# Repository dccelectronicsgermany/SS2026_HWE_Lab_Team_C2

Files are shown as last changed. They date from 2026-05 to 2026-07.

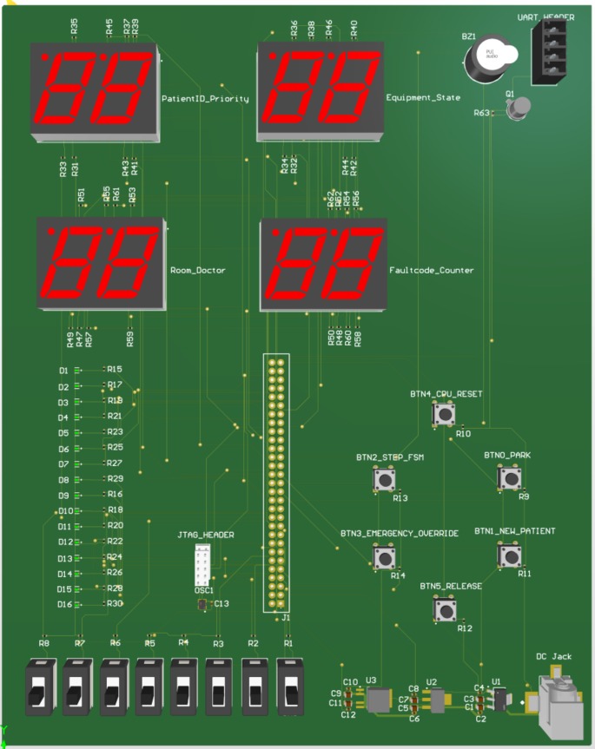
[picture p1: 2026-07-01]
hwe-lab/project/PCB_Design/Smart_Hospital_Dispatcher_3D_View.jpeg

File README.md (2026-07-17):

# FPGA-Based Smart Hospital Emergency Response Dispatcher

## Overview

This repository contains the implementation and documentation of an FPGA-based Smart Hospital Emergency Response Dispatcher developed for the Hardware Engineering Laboratory at Hochschule Hamm-Lippstadt during the Summer Semester 2026.

The system was implemented in VHDL for the Digilent Nexys A7 FPGA platform and combines digital hardware design, verification, FPGA demonstration, and Altium PCB realization.

## Team C2

- Bertrand Mungu Cho
- Daniel Chidi Chimezie
- Riwaj Ghimire
- Stephen Uzochi Obuh

## Main Features

- Patient registration and input capture
- Triage and priority encoding
- Room, doctor, and equipment allocation
- Scheduler finite-state machine
- Parking of multiple patient assignments
- Selective release of stored patients
- Emergency override
- Resource-exhaustion fault handling
- Safety supervision and alarm latching
- LED status indication
- Seven-segment display output
- UART status transmission
- Full-system reset and recovery

## Hardware Platform

- Digilent Nexys A7
- AMD Artix-7 FPGA
- 100 MHz system clock
- On-board switches, push buttons, LEDs, and seven-segment displays

## Design Structure

The FPGA design consists of ten synthesizable VHDL modules:

1. Patient acquisition
2. Priority encoder
3. Resource manager
4. Scheduler FSM
5. Patient table
6. Safety supervisor
7. LED controller
8. Seven-segment driver
9. UART controller
10. Top-level integration entity

## Verification

The project includes:

- Ten dedicated VHDL testbenches
- 114 assertion statements
- Verification of patient capture, priority mapping, allocation, release, parking, state transitions, alarms, display outputs, UART framing, and top-level integration

## Demonstrated Scenarios

The final FPGA implementation was demonstrated with the following scenarios:

1. Normal urgent-patient dispatch
2. Critical-patient handling
3. Emergency override
4. Multiple-patient parking
5. Selective patient release
6. Resource exhaustion and fault-state entry
7. Full-system reset
8. Hardware resource dashboard

## PCB Development

The Altium design package includes:

- Hierarchical schematics
- Two-layer PCB layout
- Three-dimensional PCB model
- Bill of materials
- Gerber files
- Plated and non-plated drill outputs

The PCB was developed as a manufacture-oriented design package. The final physical laboratory demonstration was performed on the Digilent Nexys A7 board.

## Tools and Technologies

- VHDL
- AMD Vivado Design Suite
- Digilent Nexys A7
- Altium Designer
- UART, 8N1, 115200 baud
- Assertion-based simulation and verification

## Project Report

The complete submitted report is available in:

`HWE_TeamC2_Final_Report_Submitted.pdf`

## Academic Context

**Course:** Hardware Engineering Laboratory  
**Institution:** Hochschule Hamm-Lippstadt  
**Semester:** Summer Semester 2026

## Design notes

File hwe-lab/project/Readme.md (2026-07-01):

# Smart Hospital Dispatcher PCB

## Overview

The **Smart Hospital Dispatcher** is a custom FPGA interface board designed as part of the **Advanced Embedded Systems Laboratory** at Hamm-Lippstadt University of Applied Sciences (HSHL).

The project demonstrates the complete hardware design workflow using **Altium Designer**, from schematic capture to PCB layout and fabrication outputs. The board interfaces with a Digilent Nexys A7 FPGA development board through a custom FPGA connector and provides user inputs, displays, communication interfaces, and power management required for implementing a smart hospital dispatcher system.

---

## Project Objectives

- Design a multi-sheet schematic using Altium Designer.
- Develop a custom FPGA interface board.
- Provide regulated power supplies for FPGA operation.
- Implement user input and output peripherals.
- Produce a manufacturable two-layer PCB.
- Generate fabrication files including Gerber files and Bill of Materials (BOM).

---

## Hardware Features

### FPGA Interface
- Custom 56-pin FPGA interface header
- Compatible with Digilent Nexys A7 (Artix-7 FPGA)

### Power Supply
- 5 V DC input
- 3.3 V regulator
- 1.8 V regulator
- 1.0 V core regulator
- Decoupling capacitors for stable power delivery

### User Inputs
- 8 Slide switches
- 6 Push buttons:
  - CPU Reset
  - New Patient
  - Step FSM
  - Emergency Override
  - Release
  - Park

### User Outputs
- 16 LEDs
- Four dual-digit 7-segment displays
- Magnetic buzzer

### Communication
- UART header
- JTAG programming header

---

## Software Used

- Altium Designer Professional 26.7.1
- GitHub

---

## Repository Structure

```
Smart_Hospital_Dispatcher/
│
├── Source Documents/
│   ├── 01_Power.SchDoc
│   ├── 02_FPGA_Core.SchDoc
│   ├── 03_Clock_Config_JTAG.SchDoc
│   ├── 04_Inputs.SchDoc
│   ├── 05_Outputs_LEDs.SchDoc
│   ├── 06_7Seg_Display.SchDoc
│   └── 07_Buzzer_UART.SchDoc
│
├── Smart_Hospital_Dispatcher.PcbDoc
├── Smart_Hospital_Dispatcher.PrjPcb
│
├── Documentation/
│   ├── Smart_Hospital_Dispatcher_Schematic.pdf
│   ├── Smart_Hospital_Dispatcher_PCB_Layout.pdf
│   └── Smart_Hospital_Dispatcher_BOM.xlsx
│
└── Gerber_Files/
    ├── Copper Layers
    ├── Solder Mask
    ├── Silkscreen
    ├── Paste Layers
    ├── Board Profile
    ├── PTH Drill Files
    └── NPTH Drill Files
```

---

## PCB Specifications

| Parameter | Value |
|---|---|
| PCB Layers | 2 |
| Design Software | Altium Designer Professional 26.7.1 |
| Power Input | 5 V DC |
| Output Voltages | 3.3 V, 1.8 V, 1.0 V |
| FPGA Interface | 56-pin custom header |
| Technology | Through-hole & Surface Mount |

---

## Project Deliverables

- Multi-sheet schematic
- PCB layout
- Bill of Materials (BOM)
- Gerber fabrication files
- Documentation PDFs

---

## Notes

The PCB was designed for educational purposes as part of the Advanced Embedded Systems Laboratory.

The FPGA is implemented through a custom interface connector to a Digilent Nexys A7 development board rather than being mounted directly on the PCB.

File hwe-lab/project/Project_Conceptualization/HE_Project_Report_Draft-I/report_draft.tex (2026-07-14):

\documentclass[conference]{IEEEtran}
\usepackage{graphicx}
\usepackage{booktabs}
\usepackage{tabularx}
\usepackage{array}
\usepackage{microtype}
\usepackage{url}
\usepackage{cite}
\usepackage{enumitem}
\usepackage{xcolor}
\setlist{nosep,leftmargin=*}
\newcommand{\HWE}{Smart Hospital Emergency Response Dispatcher}
\begin{document}
\title{Hardware Engineering Laboratory Final Report:\\FPGA-Based Smart Hospital Emergency Response Dispatcher}
\author{\IEEEauthorblockN{Team C2}
\IEEEauthorblockA{Hardware Engineering Laboratory, 6th Semester\\
Hochschule Hamm-Lippstadt, Germany\\Summer Semester 2026}}
\maketitle

\begin{abstract}
This report summarizes the complete Hardware Engineering Laboratory work completed by Team C2, from foundational combinational logic and arithmetic circuits to a modular Field-Programmable Gate Array (FPGA) system and a fabrication-ready custom printed circuit board. The final project, the \HWE, was implemented in VHDL for the Digilent Nexys A7-100T. It receives patient data, calculates priority, allocates rooms, doctors and equipment, supervises unsafe conditions, and presents status through light-emitting diodes, an eight-digit seven-segment display and Universal Asynchronous Receiver-Transmitter communication. The repository contains ten synthesizable project modules, ten dedicated testbenches with 115 assertions, a board constraint file and a generated bitstream. The laboratory demonstration successfully exercised normal dispatch, critical-patient handling, parking of multiple patients, selective release, resource exhaustion, fault indication and full reset. In parallel, a seven-sheet Altium design, two-layer printed circuit board layout, 120-line bill of materials and complete Gerber/drill outputs were produced. The work demonstrates an end-to-end engineering workflow covering specification, digital design, verification, FPGA deployment, human-machine interfacing, safety logic and electronic design automation.
\end{abstract}

\begin{IEEEkeywords}
FPGA, VHDL, finite-state machine, resource management, functional safety, Altium Designer, printed circuit board, Nexys A7.
\end{IEEEkeywords}

\section{Introduction and Scope}
The laboratory was structured as a progressive hardware-design programme. Early exercises established correct use of concurrent and behavioural VHDL, hierarchical composition and self-checking testbenches. These foundations were extended to ripple-carry arithmetic, binary-coded-decimal conversion, seven-segment decoding, clock division and synchronous counters. The final project integrated these skills into a safety-oriented cyber-physical demonstrator representing the workflow of a hospital emergency department.

The principal engineering objective was not to implement a medical device, but to demonstrate deterministic hardware control: patient requests are encoded at the board inputs; triage information is latched; resources are allocated in a controlled sequence; invalid or unsafe situations trigger a fault; and the full state is made visible to an operator. The repository, design documentation, user manual, presentation and fabrication outputs were reviewed as the evidence base for this report \cite{repo,manual,concept}.

\section{Laboratory Progression}
\subsection{Combinational Logic and Arithmetic}
The first phase implemented an XOR gate, half and full adders, and half and full subtractors. These tasks established Boolean modelling, entity/architecture separation and waveform-based validation. The next phase introduced structural reuse through a full adder constructed from half adders, a ripple-carry adder, an adder/subtractor, a binary-coded-decimal adder and a binary-coded-decimal-to-seven-segment decoder. The exercises therefore moved from isolated truth-table functions to multi-bit datapaths and hierarchical design.

\subsection{FPGA Deployment and Sequential Logic}
The arithmetic design was subsequently paired with Nexys A7 constraint files and generated bitstreams, demonstrating the transition from simulation to physical input/output mapping. Later work implemented a clock divider, a one-digit decimal counter and a two-digit decimal counter. The one-digit counter uses the 100 MHz board clock, a start/stop switch, a clear button and an active-low seven-segment output. This phase addressed clock-domain timing, human-visible update rates, synchronous control and display multiplexing.

\begin{table}[t]
\caption{Summary of Laboratory Achievements}
\label{tab:labs}
\centering
\footnotesize
\begin{tabularx}{\columnwidth}{@{}p{0.11\columnwidth}X X@{}}
\toprule
Phase & Main implementation & Engineering outcome \\
\midrule
Lab 1 & Gates, adders and subtractors & Boolean and behavioural VHDL; basic testbenches \\
Lab 2 & Ripple-carry, add/subtract, BCD adder, seven-segment decoder & Hierarchy, arithmetic datapaths and display encoding \\
Lab 4 & Altium schematic and PCB exercise & Electronic design automation and fabrication workflow \\
Lab 5 & FPGA constraints and bitstreams & Physical synthesis, pin mapping and board validation \\
Lab 7 & Clock divider and decimal counters & Sequential logic, clock scaling and display control \\
Project & Hospital dispatcher system & Modular integration, safety supervision and demonstration \\
\bottomrule
\end{tabularx}
\end{table}

\section{Final System Architecture}
The final implementation is organised as ten synthesizable VHDL modules with clear functional boundaries. The \texttt{patient\_generator} captures patient identity, type and severity. The \texttt{priority\_encoder} calculates triage priority. The \texttt{resource\_manager} maintains four-bit occupancy vectors for rooms, doctors and equipment and selects the first available resource. The \texttt{scheduler\_fsm} sequences the operational workflow. The \texttt{patient\_table} stores parked patients and their assigned resources, while the \texttt{safety\_supervisor} checks allocation and state consistency. Output handling is separated into LED, seven-segment and UART controllers, all connected by \texttt{top\_level}.

\begin{figure}[t]
\centering

\caption{Implemented dispatcher finite-state-machine workflow.}
\label{fig:fsm}
\end{figure}

The state machine in Fig.~\ref{fig:fsm} implements IDLE, RECEIVE PATIENT, TRIAGE, CHECK RESOURCES, three allocation stages, DISPATCH TEAM, MONITOR TREATMENT, RELEASE RESOURCES and FAULT. Manual stepping makes each transition observable during demonstration, whereas the treatment state advances with a severity-dependent timer. A park command returns the controller to IDLE while retaining occupied resources, enabling up to four concurrent patient records. Selective release uses a two-bit slot index to free the room, doctor and equipment associated with one parked patient.

Priority is formed from a severity base value and a type-related boost. Critical patients therefore receive the highest scheduling significance, and an emergency-override input can force escalation. The design maps room, doctor and equipment occupancy to twelve LEDs; separate LEDs indicate critical status, active treatment, system fault and a latched blinking alarm. The eight-digit display presents patient identity, severity, room, doctor, emergency indication and finite-state-machine code \cite{manual}.

\section{Safety and Deterministic Resource Control}
Safety behaviour was implemented directly in hardware rather than added only as a display feature. The supervisor detects an allocation request when the relevant resource class is already full, resource exhaustion during allocation and invalid state encodings. The immediate fault output can clear after the initiating condition disappears, but the alarm is latched until reset. The scheduler also enters FAULT when required resources are unavailable, preventing uncontrolled continuation.

The resource manager uses explicit occupancy registers and deterministic first-free selection. Allocation and release are issued as single-cycle control strobes. This creates an auditable transaction model: one controller requests an operation, one manager updates occupancy, and the safety supervisor independently observes the request and current capacity. The patient table has priority over normal finite-state-machine release indices when a parked patient is selectively released, avoiding simultaneous conflicting release paths.

\begin{figure}[t]
\centering

\caption{Demonstration scenario for complete room occupancy and transition to FAULT.}
\label{fig:fault}
\end{figure}

\section{Verification and Laboratory Demonstration}
The project includes a dedicated testbench for every synthesizable module. Together, the ten project testbenches contain 115 explicit assertions. They check priority values, patient capture, allocation and release, patient-table storage, state transitions, fault latching, display encodings, UART frame transmission and top-level integration. The integration test covers a complete dispatch-and-release cycle, parking with resources retained, and selective release of a stored patient.

The final bitstream and Nexys A7 constraint file provide implementation evidence beyond behavioural source code. During the laboratory demonstration, the board operated successfully and the team demonstrated the scenarios summarized in Table~\ref{tab:demo}. The result confirms that switch/button inputs, finite-state-machine stepping, occupancy LEDs, seven-segment status and safety responses functioned coherently on physical hardware.

\begin{table}[t]
\caption{Successful Demonstration Coverage}
\label{tab:demo}
\centering
\footnotesize
\begin{tabularx}{\columnwidth}{@{}p{0.33\columnwidth}X@{}}
\toprule
Scenario & Observed system behaviour \\
\midrule
Normal urgent patient & Full register, triage, allocate, dispatch, monitor and release sequence \\
Critical heart attack & Critical indicator, maximum priority and extended treatment interval \\
Emergency override & Input escalation to critical handling \\
Multiple patients & Parked records retained with independent resource occupancy \\
Selective release & Chosen patient slot released without disturbing other occupied slots \\
No resources & FAULT state, fault LED and blinking latched alarm \\
Full reset & Registers, resources, alarms and displays returned to ready state \\
\bottomrule
\end{tabularx}
\end{table}

\begin{figure}[t]
\centering

\caption{Critical-patient scenario used to communicate and demonstrate system behaviour.}
\label{fig:critical}
\end{figure}

\section{Altium Schematic and PCB Design}
A custom interface board was designed in Altium Designer Professional 26.7.1 to support the dispatcher concept. The design is split into seven schematic sheets: power, FPGA interface/core, clock/configuration/JTAG, inputs, LED outputs, four dual-digit seven-segment displays, and buzzer/UART. This sheet partitioning improves reviewability and supports independent checking of power, control and human-machine-interface functions \cite{schematic}.

\begin{figure*}[t]
\centering
\begin{minipage}{0.32\textwidth}\centering
\\[-1mm]
\scriptsize (a) Multi-rail power section
\end{minipage}\hfill
\begin{minipage}{0.32\textwidth}\centering
\\[-1mm]
\scriptsize (b) Switch and push-button inputs
\end{minipage}\hfill
\begin{minipage}{0.32\textwidth}\centering
\\[-1mm]
\scriptsize (c) Seven-segment display interfaces
\end{minipage}
\caption{Selected sheets from the seven-sheet Altium schematic package.}
\label{fig:schematics}
\end{figure*}

The board accepts 5 V input and includes 3.3 V, 1.8 V and 1.0 V regulator stages with local decoupling. A custom 56-pin connector interfaces to the Nexys A7. Operator controls comprise eight slide switches and six push buttons for reset, new patient, step, override, release and park. Outputs include sixteen LEDs, four dual-digit displays and a magnetic buzzer. UART and JTAG headers provide communication and programming access.

The printed circuit board is a two-layer mixed through-hole/surface-mount design. The bill of materials contains 120 populated designator lines representing 20 unique component descriptions. Manufacturing outputs include top and bottom copper, solder mask, paste and legend layers, board profile, plated-through-hole and non-plated-through-hole drill data, an aperture file and the bill of materials \cite{pcb,bom}. This is a complete fabrication handoff rather than only a schematic concept.

\begin{figure}[t]
\centering

\caption{Altium three-dimensional rendering of the Smart Hospital Dispatcher interface PCB.}
\label{fig:pcb3d}
\end{figure}

\begin{figure}[t]
\centering

\caption{Routed two-layer PCB layout and component placement.}
\label{fig:layout}
\end{figure}

\section{Engineering Assessment}
The strongest outcome is the continuity of the workflow. The team did not stop at an algorithmic finite-state-machine model: the work connects specification, VHDL decomposition, module-level and integration-level verification, constraint mapping, bitstream generation, physical demonstration, user documentation, schematic capture, printed circuit board layout and fabrication files. Functional concerns were also separated appropriately. Scheduling, resource accounting, patient storage, safety monitoring and user-interface encoding are independent modules, reducing coupling and making faults easier to localize.

The evidence also supports several quality observations. First, the project uses self-checking testbenches rather than relying only on waveform inspection. Second, fault and alarm behaviour is intentionally different: fault reflects the present condition, whereas alarm memory requires operator reset. Third, resource assignment is deterministic, which makes demonstrations repeatable. Fourth, the manual defines exact switch settings, button sequences and expected display/LED results, enabling reproducible acceptance testing.

Remaining engineering work is mainly associated with productisation. The Altium board should undergo a formal electrical-rule/design-rule review, power-budget and thermal calculation, connector pin-by-pin verification against the Nexys A7 electrical limits, signal-integrity review and manufactured-board bring-up. For the FPGA design, useful extensions would include automated synthesis/timing reports under version control, constrained-random or coverage-driven verification, debounce timing characterization, UART receive commands and persistent logging. These are logical next steps and do not diminish the achieved laboratory objective.

\section{Conclusion}
Team C2 completed a broad and coherent Hardware Engineering Laboratory portfolio. The work progressed from elementary combinational circuits to arithmetic subsystems, FPGA-mapped counters and a modular emergency-dispatch controller. The final system contains ten VHDL modules, ten self-checking testbenches, 115 assertions, a Nexys A7 bitstream and a successful physical demonstration covering normal, critical, multi-patient and fault scenarios. The accompanying Altium package adds seven schematic sheets, a routed two-layer printed circuit board, a 120-line bill of materials and full manufacturing data. Collectively, these deliverables demonstrate technical competence in digital logic, synchronous design, verification, FPGA implementation, safety-oriented control, human-machine interfacing and printed circuit board engineering.

\begin{thebibliography}{00}
\bibitem{repo} Team C2, ``SS2026 HWE Laboratory Repository,'' VHDL sources, testbenches, constraints and bitstreams, HSHL, 2026.
\bibitem{manual} Team C2, ``FPGA-Based Smart Hospital Emergency Response Dispatcher: User Manual,'' 2026.
\bibitem{concept} Team C2, ``FPGA-Based Smart Hospital Emergency Response Dispatcher Using the Digilent Nexys A7,'' project conceptualization document, 2026.
\bibitem{schematic} Team C2, ``Smart Hospital Dispatcher Schematics,'' seven-sheet Altium schematic export, rev. 1, June 2026.
\bibitem{pcb} Team C2, ``Smart Hospital Dispatcher PCB Layout and Gerber Fabrication Package,'' 2026.
\bibitem{bom} Team C2, ``Smart Hospital Dispatcher Bill of Materials,'' Altium BOM export, 2026.
\end{thebibliography}
\end{document}

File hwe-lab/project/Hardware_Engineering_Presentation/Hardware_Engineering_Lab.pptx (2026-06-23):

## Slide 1

FPGA HARDWARE RESOURCE DASHBOARD

FPGA HOSPITAL DISPATCHER

SCENARIO 09 / 09

ROOMS

Room 1

Room 2

Room 3

Room 4

Occuppied

DOCTORS

Doctor 1

Doctor 2

Doctor 3

Doctor 4

Free

Fault (F)

EQUIPMENT

ECG Unit

Defib

Ventilator

Monitor

Emergency (E)

BUSY

BUSY

BUSY

BUSY

BUSY

FREE

FREE

FREE

FREE

FREE

BUSY

FREE

CRITICAL ALERTS

Patient 7 — Heart Attack

Override active (BTNR)

LED12 critical flag

Verilog FSM · Nexys FPGA · Patient Dispatch Controller

TREATMENT STATUS

Live LED telemetry — green free · red busy · amber fault · pink emergency

CRITICAL

Patient 1

Monitoring

EMERGENCY

Patient 2

Dispatch

ON

Patient 7

Critical Care

9 / 9

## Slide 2

FPGA DISPATCHER STATE MACHINE

Animate each state in sequence using PowerPoint Morph — the FSM loops back to IDLE.

FPGA HOSPITAL DISPATCHER

SCENARIO 08 / 09

IDLE

1

RECEIVE PATIENT

2

TRIAGE

3

CHECK RESOURCES

4

ALLOCATE ROOM

5

ALLOCATE DOCTOR

6

ALLOCATE EQUIPMENT

7

DISPATCH

8

MONITOR

9

RELEASE

10

RELEASE → loops back to IDLE

11-state cycle: IDLE → RECEIVE → TRIAGE → CHECK → ROOM → DOCTOR → EQUIPMENT → DISPATCH → MONITOR → RELEASE → IDLE

Verilog FSM · Nexys FPGA · Patient Dispatch Controller

8 / 9

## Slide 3

SCENARIO 1 — NORMAL STROKE PATIENT (URGENT)

FPGA HOSPITAL DISPATCHER

SCENARIO 01 / 09

PATIENT ID

1

TYPE

Stroke {SW3=1,SW2=0}

SEVERITY

Urgent{SW1=0,SW0=1}

Patient Arrives

Patient icon enters the hospital

1

Allocate Room

Room 1 lights green

5

Treatment

Heart monitor blinking

9

Register Patient (BTNL)

Registration desk appears

Allocate Doctor

Doctor 1 icon appears

Release Resources

Room, doctor & equipment freed

2

6

10

Triage

Nurse icon appears

3

Allocate Equipment

ECG machine appears

7

System Returns to IDLE

FPGA returns to ready state

★

Check Resources

Magnifier scans resources

4

Dispatch Team

Ambulance moves to patient

8

Verilog FSM · Nexys FPGA · Patient Dispatch Controller

1 / 9

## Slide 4

SCENARIO 2 — CRITICAL HEART ATTACK

FPGA HOSPITAL DISPATCHER

SCENARIO 02 / 09

Patient Arrives

1

Equipment Assigned

7

PATIENT ID

7

Critical Flag Appears

Dispatch

2

8

TYPE

Heart Atk

SEVERITY

Critical

LED12 Turns ON

3

Treatment Timer Runs Longer

9

SCREEN FLASHES RED ONCE

triggered when Severity = Critical

Priority Score → Maximum

4

Resources Released

10

TREATMENT COUNTDOWN

4s

extended timer for critical care

Room Assigned

5

Critical Flag Removed

11

Doctor Assigned

6

Verilog FSM · Nexys FPGA · Patient Dispatch Controller

2 / 9

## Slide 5

SCENARIO 4 — PARKING MULTIPLE PATIENTS

Objective: demonstrate FPGA resource management across simultaneous patients.

FPGA HOSPITAL DISPATCHER

SCENARIO 04 / 09

PATIENT 1

Room 1

Doctor 1

Equipment 1

LEDs 0, 4, 8 ON

PATIENT 2

Room 2

Doctor 2

Equipment 2

LEDs 1, 5, 9 ON

PATIENT 3

Room 3

Doctor 3

Equipment 3

LEDs 2, 6, 10 ON

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
Each patient parked with BTNU → resources held in FPGA slots

Verilog FSM · Nexys FPGA · Patient Dispatch Controller

HOSPITAL DASHBOARD — ALL RESOURCES BUSY

Room 1

BUSY

Room 2

BUSY

Room 3

BUSY

Doctor 1

BUSY

Doctor 2

BUSY

Doctor 3

BUSY

4 / 9

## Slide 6

SCENARIO 5 — SELECTIVE PATIENT RELEASE

FPGA HOSPITAL DISPATCHER

SCENARIO 05 / 09

3 Patients Parked

Room1 · Room2 · Room3 busy

1

RESOURCE STATE AFTER RELEASE

Patient 1 · Room1 / Doctor1 / Eq1

Patient 2 · Room2 / Doctor2 / Eq2

Patient 3 · Room3 / Doctor3 / Eq3

SLOT 2 RESOURCES NOW FREE

Room 2 → Available

Doctor 2 → Available

Equipment 2 → Available

ACTIVE

Select Slot 2

SW[1:0] = 01

2

RELEASED

Hold BTND

Arm the release

3

ACTIVE

Press BTNC

Confirm release

4

Release Patient 2

LED1 · LED5 · LED9 turn OFF

Verilog FSM · Nexys FPGA · Patient Dispatch Controller

5

5 / 9

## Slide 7

SCENARIO 6 — NO RESOURCES AVAILABLE

FPGA HOSPITAL DISPATCHER

SCENARIO 06 / 09

Rooms 1–4 Occupied

All four rooms busy

1

ROOM OCCUPANCY

Fifth Patient Arrives

Enters the queue

Room 1

BUSY

Room 2

BUSY

Room 3

BUSY

Room 4

BUSY

2

Check Resources

Scanning availability

3

SYSTEM FAULT

NO RESOURCES AVAILABLE

FSM state: FAULT — system locked

Dramatic effect: large warning overlay + screen shake.

No Rooms Available

Allocation fails

4

FSM Enters FAULT

Screen shakes

5

LED14 ON

LED15 BLINK

System Locked

LED14 ON · LED15 blinking

Verilog FSM · Nexys FPGA · Patient Dispatch Controller

6

6 / 9

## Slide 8

SCENARIO 7 — FULL SYSTEM RESET

FPGA HOSPITAL DISPATCHER

SCENARIO 07 / 09

BEFORE — FAULT STATE

FSM = FAULT

Alarm Active

Resources Busy

LEDs Lit

AFTER — READY STATE

All LEDs OFF

Rooms Freed

Doctors Freed

Equipment Freed

DISPLAY → IDLE

System Ready

CPU_RESETN

PRESS

Resets all registers, frees rooms / doctors / equipment, clears LEDs.

Verilog FSM · Nexys FPGA · Patient Dispatch Controller

7 / 9

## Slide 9

EMERGENCY OVERRIDE (BTNR)

FPGA HOSPITAL DISPATCHER

SCENARIO 03 / 09

STORY: A normal patient suddenly becomes critical — the doctor forces an override.

Normal Patient Enters

Severity = Normal

1

Fast-Track Allocation

Room · doctor · equipment

6

ESCALATION PATH

NORMAL

OVERRIDE

CRITICAL

Doctor Presses BTNR

Emergency override pressed

2

Dispatch

Team sent immediately

7

System Forces Critical

Red emergency symbol appears

3

Treatment

Critical care delivered

8

LED12 ON

Critical indicator active

4

Release

Resources returned to pool

9

Priority Becomes Highest

Jumps to front of queue

5

Verilog FSM · Nexys FPGA · Patient Dispatch Controller

3 / 9

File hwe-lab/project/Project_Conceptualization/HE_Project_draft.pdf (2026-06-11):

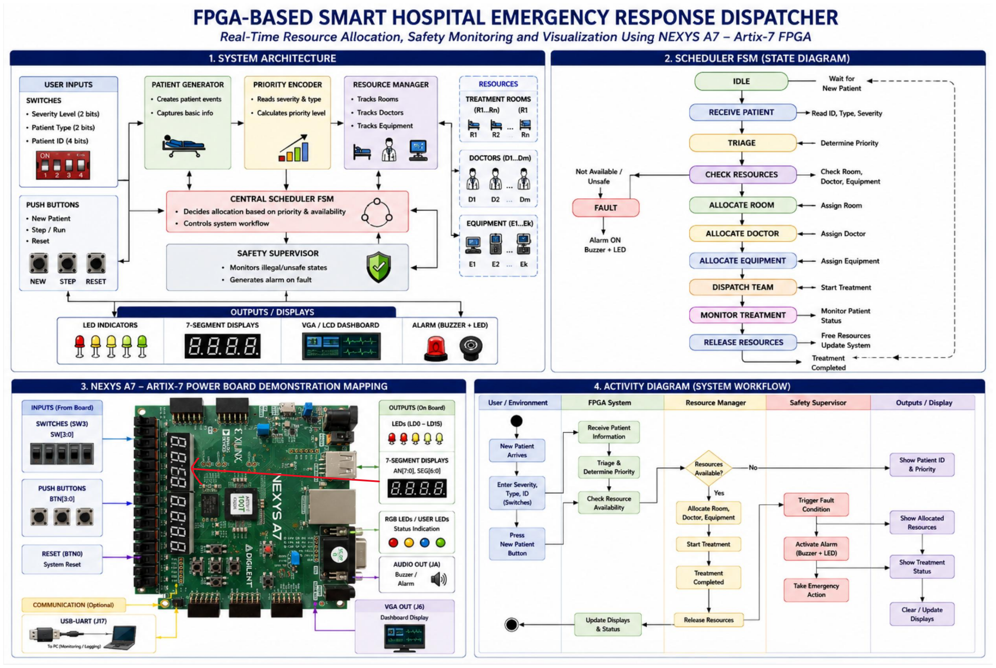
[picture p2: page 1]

FPGA-Based Smart Hospital Emergency Response Dispatcher Using the Digilent Nexys A7 (Artix-7 XC7A100T)

### 1. Project Overview

The FPGA-Based Smart Hospital Emergency Response Dispatcher is a real-time embedded system implemented entirely in VHDL on the Digilent Nexys A7 FPGA board. The purpose of the system is to simulate the operation of a hospital emergency department where patients arrive with different levels of urgency and must be assigned available resources such as treatment rooms, doctors, and medical equipment.
The FPGA acts as an intelligent hospital dispatcher that receives patient information through board inputs, prioritizes patients according to severity, allocates resources, monitors system safety, and displays all system activities on LEDs, seven-segment displays, UART communication, and optionally a VGA dashboard.
This project combines concepts from:
- FPGA Design
- VHDL
- Embedded Systems
- Cyber-Physical Systems
- Functional Safety
- Real-Time Systems
- Resource Scheduling
- Finite State Machines
The project is intended to demonstrate a realistic safety-critical control system similar to those used in hospitals, airports, industrial automation, and transportation systems.

### 2. System Objective

The objective of the project is to develop a real-time hospital emergency management system capable of:

- Receiving new patient requests
- Determining patient priority
- Allocating rooms
- Allocating doctors
- Allocating equipment
- Monitoring treatment progress
- Releasing resources after treatment
- Detecting unsafe conditions
- Activating alarms during faults
- Displaying system status on the FPGA board

### 3. Overall System Architecture

The system consists of the following major modules: Hospital Dispatcher
│

├── Input Controller

├── Patient Generator

├── Priority Encoder

├── Resource Manager

├── Scheduler FSM

├── Safety Supervisor

├── LED Controller

├── Seven Segment Driver

├── UART Interface
└── VGA Dashboard (Optional)

The information flow is:
Inputs
↓
Patient Generator
↓
Priority Encoder
↓
Resource Manager
↓
Scheduler FSM
↓
Safety Supervisor
↓
Outputs

### 4. User Inputs

The user interacts with the system through the Nexys A7 board.

Switch Inputs
The slide switches represent patient information. SW0-SW1
Patient Severity
00 = Normal
01 = Urgent
10 = High Priority
11 = Critical Emergency
SW2-SW3
Patient Type
00 = General
01 = Accident
10 = Stroke
11 = Heart Attack
SW4-SW7
Patient Identification Number 0000 – 1111
Patient IDs 0 – 15

Push Buttons
BTN0

System Reset
Returns the entire system to the IDLE state. BTN1
New Patient
Generates a new patient arrival event. BTN2
Step FSM
Executes one state transition at a time for demonstration purposes. BTN3
Emergency Override
Immediately prioritizes critical emergency patients.

### 5. Patient Generator Module

The Patient Generator creates patient records from the board inputs. Generated information includes:
Patient ID
Patient Type
Patient Severity
Arrival Time
Example:
Patient ID = 12

Patient Type = Heart Attack
Severity = Critical
The generated information is forwarded to the Priority Encoder.

### 6. Priority Encoder Module

The Priority Encoder performs triage.
Triage is the process used in hospitals to determine which patient should be treated first. Example:
Patient A = Critical
Patient B = Normal
Patient C = Urgent
Output order:
Patient A
Patient C
Patient B
The Priority Encoder always gives preference to the highest-severity patient.

### 7. Resource Manager Module

The Resource Manager keeps track of available hospital resources. Treatment Rooms
R1

R2
R3
R4
Doctors
D1
D2
D3
D4
Equipment
E1
E2
E3
E4
The module stores occupancy information and continuously updates resource availability.

### 8. Scheduler FSM

The Scheduler Finite State Machine is the central controller of the system. The FSM executes the following sequence:
IDLE
↓
RECEIVE_PATIENT

↓
TRIAGE
↓
CHECK_RESOURCES
↓
ALLOCATE_ROOM
↓
ALLOCATE_DOCTOR
↓
ALLOCATE_EQUIPMENT
↓
DISPATCH_TEAM
↓
MONITOR_TREATMENT
↓
RELEASE_RESOURCES
↓
IDLE
If a fault occurs:
CHECK_RESOURCES
↓

FAULT

State Descriptions
IDLE
Waiting for a new patient. RECEIVE_PATIENT
Reads patient information from switches. TRIAGE
Calculates patient priority.
CHECK_RESOURCES
Verifies room, doctor, and equipment availability. ALLOCATE_ROOM
Assigns treatment room.
ALLOCATE_DOCTOR
Assigns doctor.
ALLOCATE_EQUIPMENT
Assigns medical equipment. DISPATCH_TEAM
Begins treatment.
MONITOR_TREATMENT
Tracks treatment progress.

RELEASE_RESOURCES
Returns all resources to the available pool. FAULT
Activates alarms and safety procedures.

### 9. Safety Supervisor

The Safety Supervisor continuously monitors system operation. The module checks for:
Double Allocation
Two patients assigned to the same room. Doctor Conflict
One doctor assigned to multiple patients. Equipment Conflict
One equipment unit assigned multiple times. Resource Exhaustion
No room available.
No doctor available.
No equipment available.
If any fault is detected:
LED14 = ON
LED15 = ON

Alarm = ON

### 10. Nexys A7 FPGA Board Mapping

The system is mapped directly to the Digilent Nexys A7 FPGA board. Switches
SW0-SW1 → Severity
SW2-SW3 → Patient Type
SW4-SW7 → Patient ID
Push Buttons
BTN0 → Reset
BTN1 → New Patient
BTN2 → Step FSM
BTN3 → Emergency Override
LEDs
Room Status
LED0 → Room 1
LED1 → Room 2
LED2 → Room 3
LED3 → Room 4
Doctor Status
LED4 → Doctor 1

LED5 → Doctor 2
LED6 → Doctor 3
LED7 → Doctor 4
Equipment Status
LED8 → Equipment 1
LED9 → Equipment 2
LED10 → Equipment 3
LED11 → Equipment 4
System Status
LED12 → Critical Patient
LED13 → Treatment Active
LED14 → Fault
LED15 → Alarm

### 11. Seven Segment Display Mapping

The Nexys A7 contains eight seven-segment displays. AN0 → Patient ID
AN1 → Priority
AN2 → Room Number
AN3 → Doctor Number
AN4 → Equipment Number

AN5 → FSM State
AN6 → Fault Code
AN7 → System Counter

### 12. UART Communication

The UART interface provides monitoring and debugging. Example terminal output:
Patient 12 Arrived
Severity = Critical
Room Assigned = R2
Doctor Assigned = D4
Equipment Assigned = E1
Treatment Started
Treatment Completed
Resources Released

### 13. VGA Dashboard (Optional)

The VGA interface displays a real-time hospital dashboard. Example:
SMART HOSPITAL DASHBOARD

----------------------------------Patient ID : 12
Priority : Critical
Room | : R2
Doctor | : D4
Equipment : E1
System State : Treatment
This significantly improves the demonstration quality.

### 14. Activity Flow

The system operates according to the following workflow: Patient Arrives
↓
Read Inputs
↓
Generate Patient
↓
Perform Triage
↓
Check Resources

↓
Resources Available?
/ \
YES | NO
Allocate FAULT
Resources |
Treatment Alarm
Monitor
Treatment
Release
Resources
Update
Displays
Return to IDLE

### 15. Development Process

Phase 1
Requirements Analysis
Define:
- Patients
- Rooms
- Doctors
- Equipment
- Safety Requirements

Phase 2
System Architecture
Create block diagrams and system decomposition.

Phase 3
FSM Design
Design all states and transitions.

Phase 4
VHDL Module Development
Create:

patient_generator.vhd
priority_encoder.vhd
resource_manager.vhd
scheduler_fsm.vhd
safety_supervisor.vhd
seven_segment_driver.vhd
led_controller.vhd
uart_controller.vhd

Phase 5
Simulation
Create testbenches.
Test:
- Normal patient
- Critical patient
- Resource exhaustion
- Safety violations

Phase 6
Hardware Integration
Create:

top_level.vhd
Connect all modules.

Phase 7
Synthesis and Bitstream Generation Use Xilinx Vivado to:
Synthesize
Implement
Generate Bitstream

Phase 8
FPGA Demonstration
Program the Nexys A7 board and demonstrate: Scenario 1
Normal Patient
Scenario 2
Critical Emergency
Scenario 3
Resource Exhaustion
Scenario 4
Emergency Override

Scenario 5
Safety Fault Detection

### 16. Expected Learning Outcomes

After completing this project, the team will have demonstrated:
- Finite State Machine Design
- VHDL Development
- FPGA Hardware Design
- Real-Time Scheduling
- Resource Allocation Algorithms
- Functional Safety Concepts
- UART Communication
- VGA Display Control
- Verification and Testing
- Cyber-Physical Systems Engineering
- Hardware/Software Co-Design Principles
This makes the FPGA-Based Smart Hospital Emergency Response Dispatcher a highly creative, industrially relevant, and technically challenging FPGA project that can be fully demonstrated on the Digilent Nexys A7 Artix-7 FPGA board.

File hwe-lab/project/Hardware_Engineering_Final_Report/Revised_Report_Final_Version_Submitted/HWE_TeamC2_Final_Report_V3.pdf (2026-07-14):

# FPGA-Based Smart Hospital Emergency Response Dispatcher:

VHDL Design, Verification, FPGA Demonstration,

# and Altium PCB Realization

Hardware Engineering Laboratory – Team C2 Bertrand Mungu Cho, Daniel Chidi Chimezie, Riwaj Ghimire, Stephen Uzochi Obuh Hochschule Hamm-Lippstadt, Germany Summer Semester 2026

Abstract—This paper documents the development and successful laboratory demonstration of an FPGA-based Smart Hospital Emergency Response Dispatcher. The system was implemented in VHDL for the Digilent Nexys A7 platform and integrates patient registration, triage priority encoding, room/doctor/equipment allocation, patient parking, selective release, emergency override, fault supervision, LED indication, seven-segment visualization, and UART status transmission. The repository contains ten synthesizable VHDL modules, ten dedicated testbenches, and 114 assertion statements. The FPGA implementation was complemented by a seven-sheet Altium schematic design, a two-layer printed circuit board (PCB), a three-dimensional PCB model, a bill of materials, and complete Gerber and drill outputs. The final laboratory demonstration confirmed the intended operating scenarios. Each design and validation figure is presented individually to preserve readability and provide traceable evidence of the team’s work. Index Terms—FPGA, VHDL, Nexys A7, Artix-7, finite-state machine, hospital dispatcher, Altium Designer, PCB, hardware verification.

I. INTRODUCTION

Field-programmable gate arrays (FPGAs) provide deterministic parallel processing, direct hardware access, and precise state-machine control. These characteristics make them suitable for teaching digital design and for prototyping resourcemanagement controllers. Team C2 developed a Smart Hospital Emergency Response Dispatcher that models the reception, triage, allocation, treatment, parking, release, and fault-handling stages of an emergency department.
The target platform was the Digilent Nexys A7, based on an AMD Artix-7 FPGA and equipped with a 100-MHz clock, switches, push buttons, LEDs, seven-segment displays, and communication interfaces [1], [2]. The RTL was written in accordance with IEEE VHDL and multivalue logic standards [3], [4]. Vivado Design Suite was used for simulation, synthesis, constraints, implementation, and bitstream generation following the vendor design flow [5]–[8].
The work demonstrates an end-to-end hardware engineering process: modular RTL development, assertion-based verification, FPGA programming, interactive laboratory validation, schematic capture, PCB layout, three-dimensional inspection, and manufacture-oriented output generation. Detailed postimplementation Vivado records are intentionally excluded from this report; the focus is the verified design architecture, functional scenarios, PCB realization, and the team’s final hardware demonstration.

II. DEVELOPMENT PATH AND SYSTEM ARCHITECTURE

The laboratory activities progressed from elementary combinational logic through arithmetic circuits, clocked counters, FPGA constraints, and PCB design before integration into the final project. This staged approach reduced integration risk and established reusable design skills [9], [10].
The final system is structurally divided into ten synthesizable modules: patient acquisition, priority encoding, resource management, scheduler finite-state machine (FSM), patient table, safety supervisor, LED controller, seven-segment driver, UART controller, and the top-level integration entity. The architecture captures patient data, computes a priority, tests resource availability, allocates room/doctor/equipment indices, and exposes the current state through board outputs.
Figure 1 presents the dispatcher state progression. The sequence begins in IDLE, accepts a patient, performs triage, checks available resources, allocates the required resources, dispatches treatment, monitors the patient, releases resources, and returns to the initial state. Explicit fault and emergency paths provide defined behavior when normal scheduling cannot continue.
Figure 2 shows the same operating cycle as a presentationoriented state sequence used during the demonstration. It makes the progression from reception to release visible to observers and supports the explanation of the controller’s temporal behavior.

III. RTL DESIGN AND VERIFICATION

The patient_generator synchronizes external inputs and captures a new transaction on a detected control edge. The priority_encoder maps patient type and severity to scheduling information. The resource_manager maintains occupancy vectors for four rooms, four doctors, and four

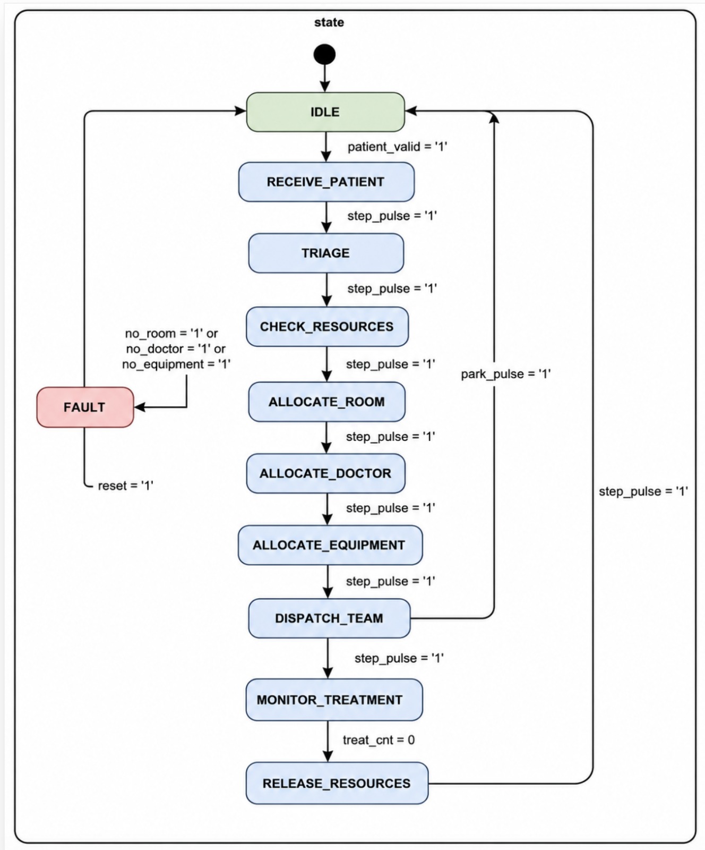
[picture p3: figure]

Fig. 1. Dispatcher finite-state-machine workflow used to structure the complete patient-handling cycle.

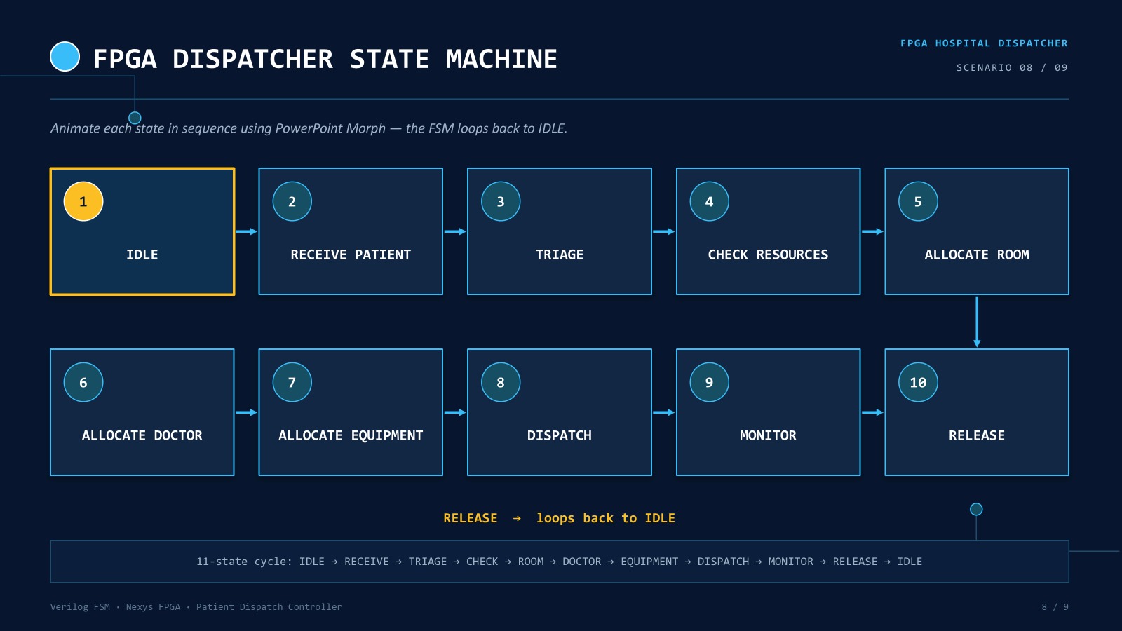
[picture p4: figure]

Fig. 2. Demonstration view of the sequential dispatcher states from patient reception to resource release.

equipment units. The scheduler_fsm sequences all control actions, while the patient_table stores up to four parked assignments for later selective release.
The safety_supervisor latches abnormal conditions, the led_controller maps occupancy and alarms to the 16 board LEDs, and the seven_segment_driver multiplexes status information. The uart_controller provides an 8N1 serial output at 115200 baud, and top_level integrates the design and board interface.
Verification was performed with one dedicated testbench per synthesizable module. The ten testbenches contain 114 VHDL assertion statements covering input capture, priority mapping, allocation and release, patient parking, state transitions, display encoding, alarm latching, LED mapping, UART framing,

TABLE I
FUNCTIONAL VERIFICATION SCOPE
Function | Verified behavior
Patient acquisition | Synchronized capture and single-event re-
| sponse
Priority logic | Severity/type combinations mapped cor-
| rectly
Resource manager | Allocation, occupancy, exhaustion, and re-
| lease
Scheduler FSM | Normal, parking, emergency, fault, and reset
| paths
Patient table | Multi-slot storage and selective release
Indicators | LED, alarm blink, and seven-segment out-
| puts
UART | Start/data/stop framing and transmission
| sequencing
Top-level | Integrated interaction of controls and re-
| sources

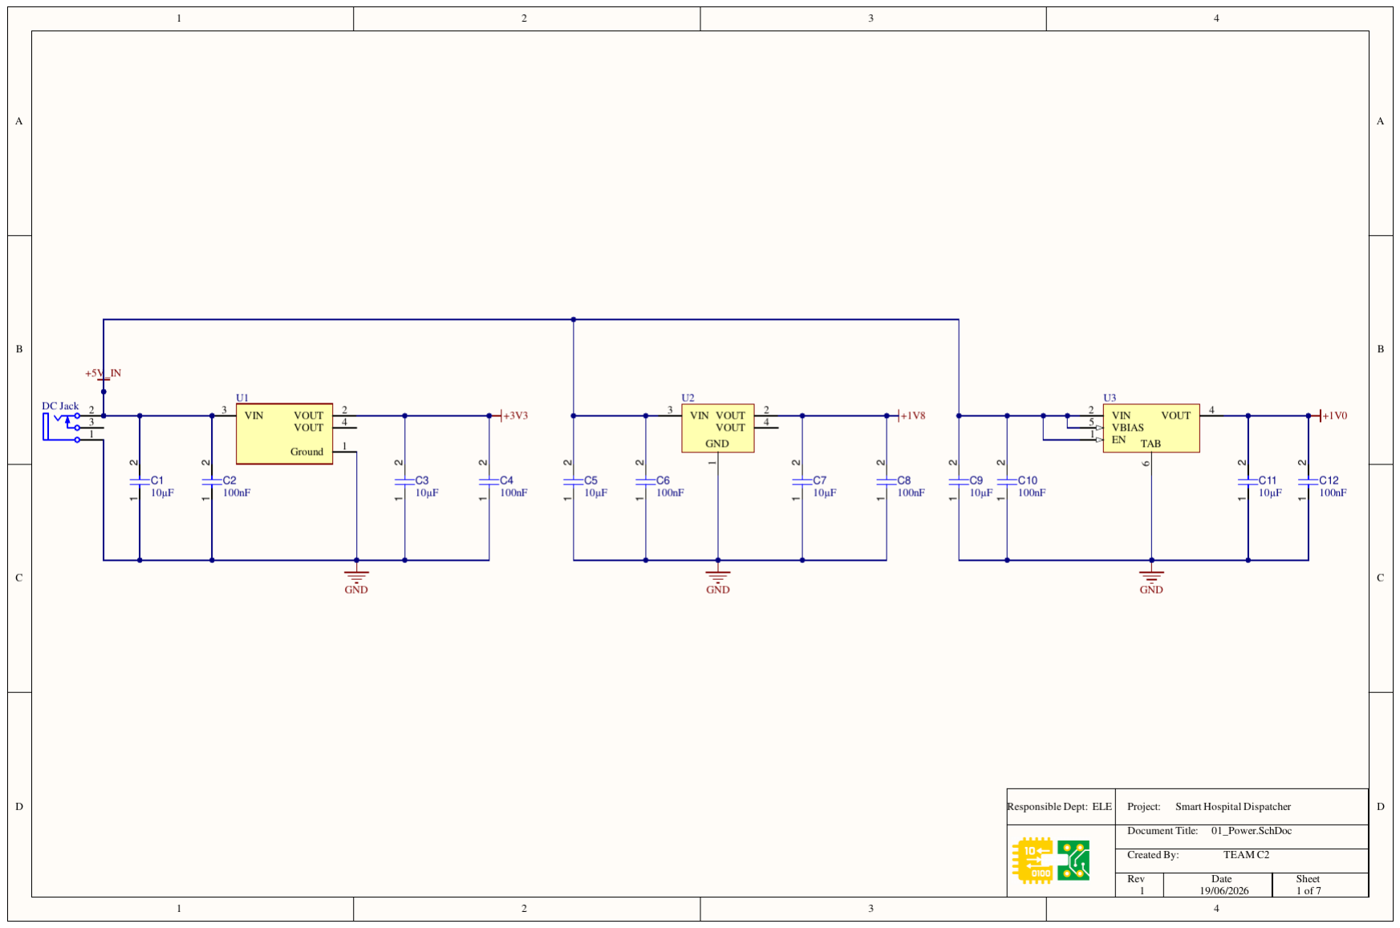
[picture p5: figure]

Fig. 3. Altium power-supply schematic used for the Smart Hospital Dispatcher interface board.

and top-level behavior. This modular strategy improves fault localization and avoids relying only on a final demonstration.

IV. ALTIUM SCHEMATIC AND PCB REALIZATION
The custom interface-board design was developed in Altium Designer. The schematic set is hierarchically separated into power, input/control, display/output, FPGA interface, clock/configuration, and communication functions. This organization supports reviewability and traceability from logical function to PCB connectivity [11].
Figure 3 shows the power section. It provides the regulated supply structure and local decoupling needed by the digital interfaces. Power-domain separation and clear rail naming are important because the board combines logic, display, and peripheral loads.
The user-input interface in Fig. 4 connects slide switches and push buttons to the FPGA-facing signals. These inputs represent patient data, severity, resource-control operations, emergency override, release selection, and reset functions. Figure 5 presents the display and indication circuitry. The implementation exposes system states through LEDs and seven-

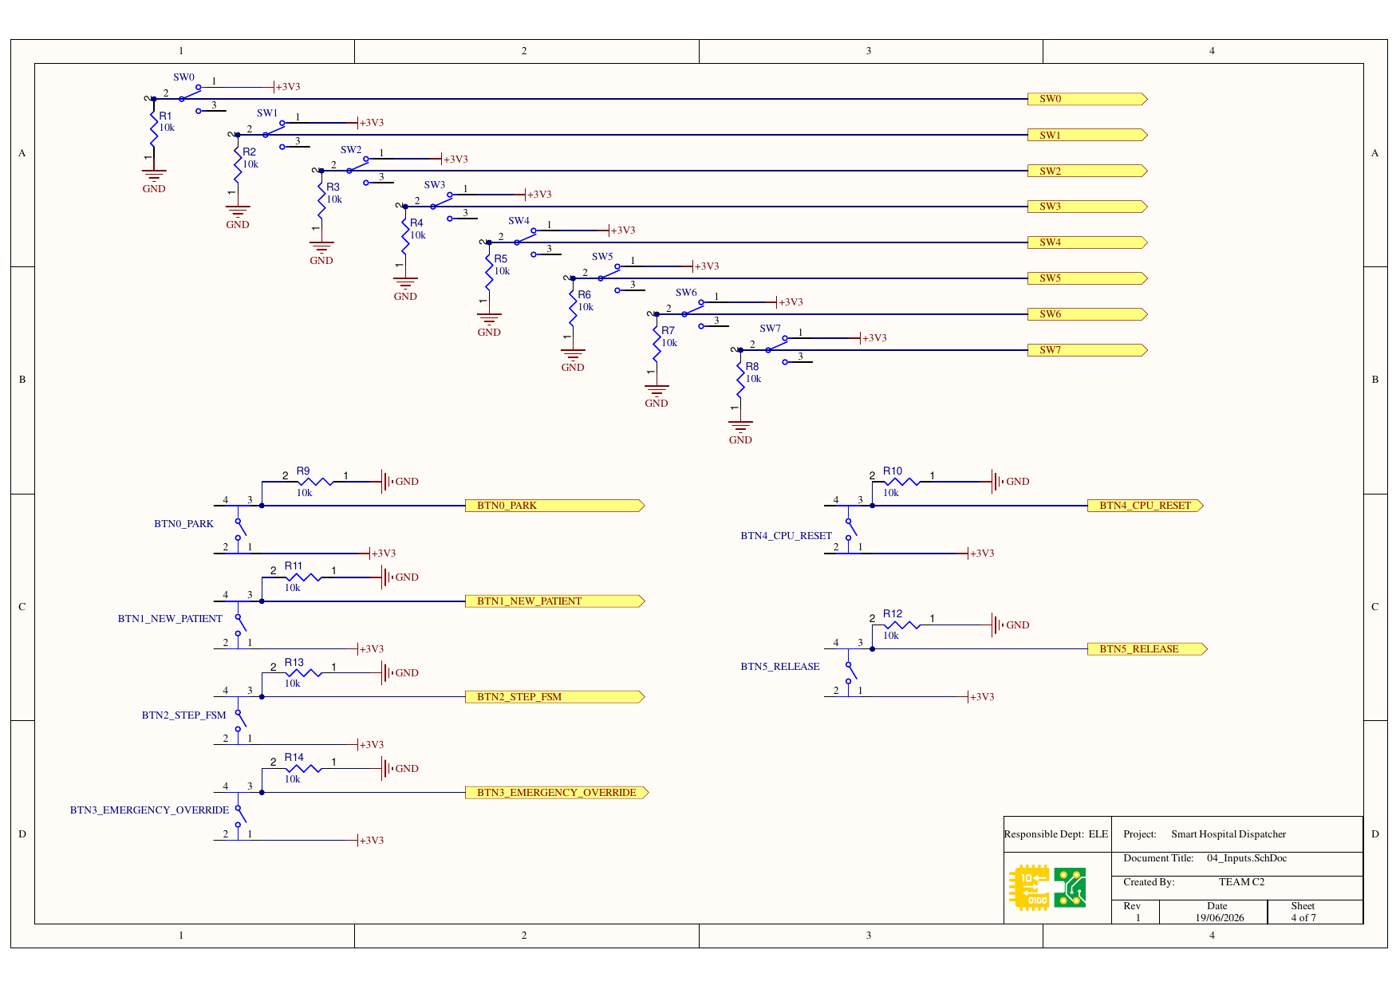
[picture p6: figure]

Fig. 4. Altium input-interface schematic for switches and push-button controls.

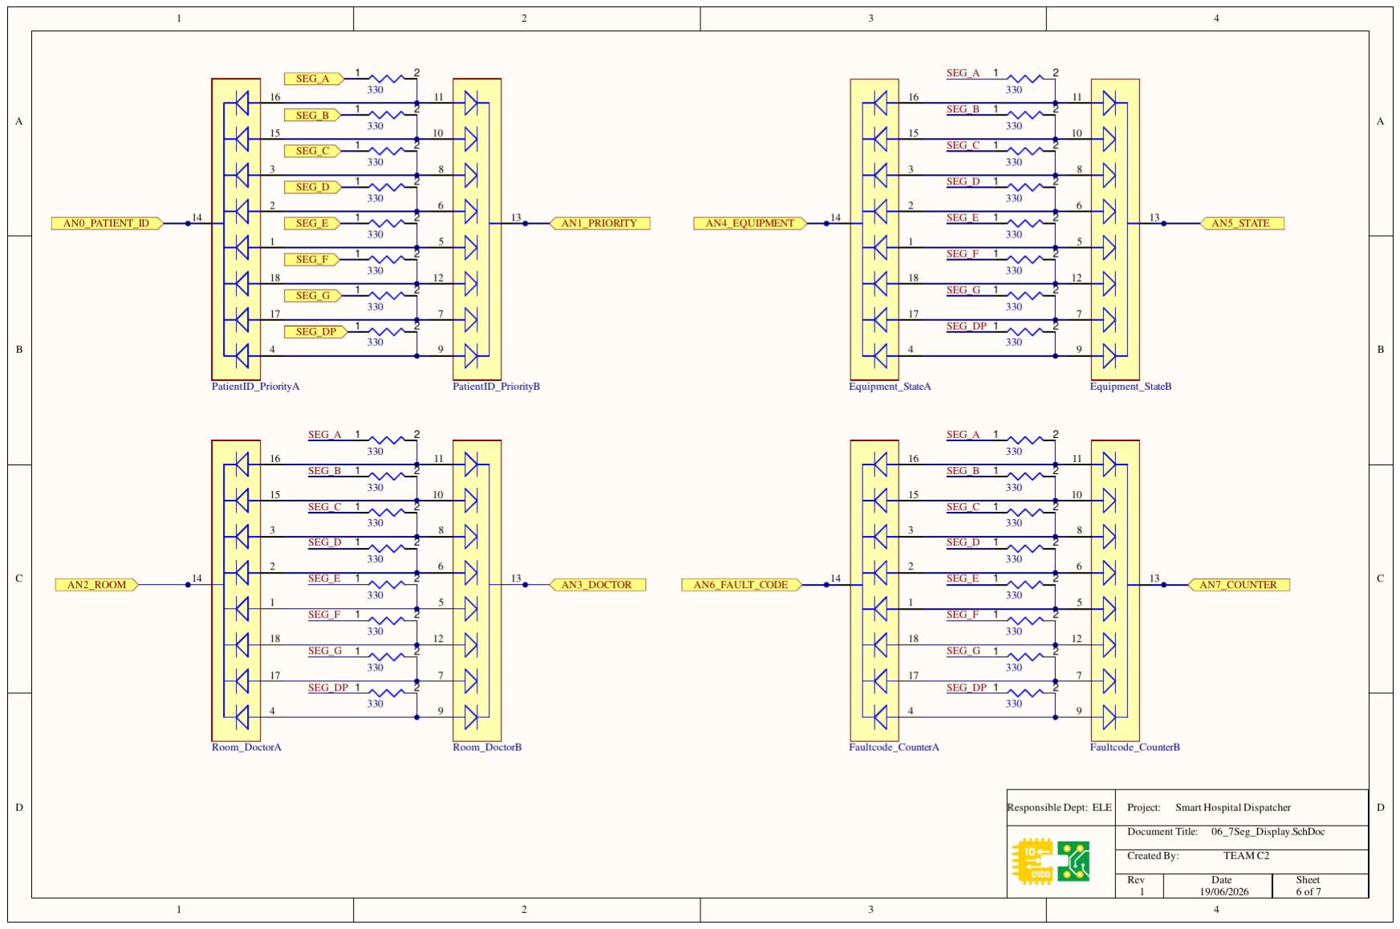
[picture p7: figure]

Fig. 5. Altium display-interface schematic for visual status and seven-segment outputs.

segment displays, allowing occupancy, fault, priority, and scheduler information to be observed during testing.
The routed two-layer PCB is shown in Fig. 6. Component placement keeps user controls and indicators accessible while routing the FPGA-interface signals toward the board connector. The design package includes top and bottom copper, solder mask, legend, paste, board profile, plated-through-hole drill, and non-plated-through-hole drill outputs.
Figure 7 provides the three-dimensional board review. The model enables inspection of connector orientation, control accessibility, display placement, board proportions, and potential mechanical conflicts before fabrication.
V. LABORATORY DEMONSTRATION AND FUNCTIONAL SCENARIOS

The generated bitstream was programmed on the Nexys A7 and evaluated interactively in the laboratory. Figure 8 is the team’s final working hardware image and is the physical

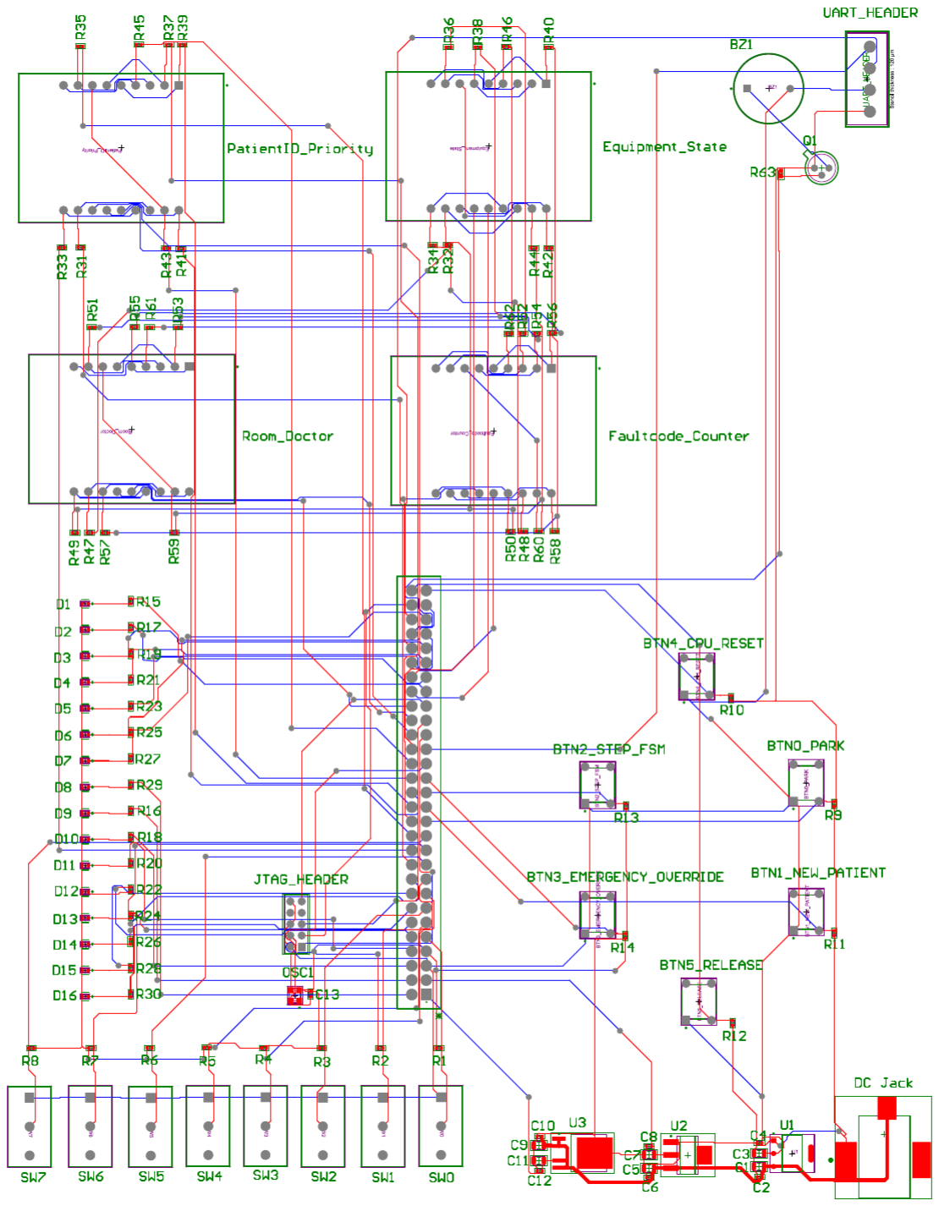
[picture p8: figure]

Fig. 6. Individually presented two-layer PCB layout exported from Altium Designer.


Fig. 7. Three-dimensional Altium rendering of the custom Smart Hospital Dispatcher PCB.

realization evidence used in this report. It replaces all non-team realization images.
The functional scenarios were prepared as individual visual records. They are not combined into a collage, allowing every sequence and label to remain readable.
A. Normal Patient Dispatch

Figure 9 documents the normal urgent-patient path. The system captures the patient, performs triage, checks resources, allocates a room, doctor, and equipment, dispatches the team, enters treatment, releases the resources, and returns to IDLE.

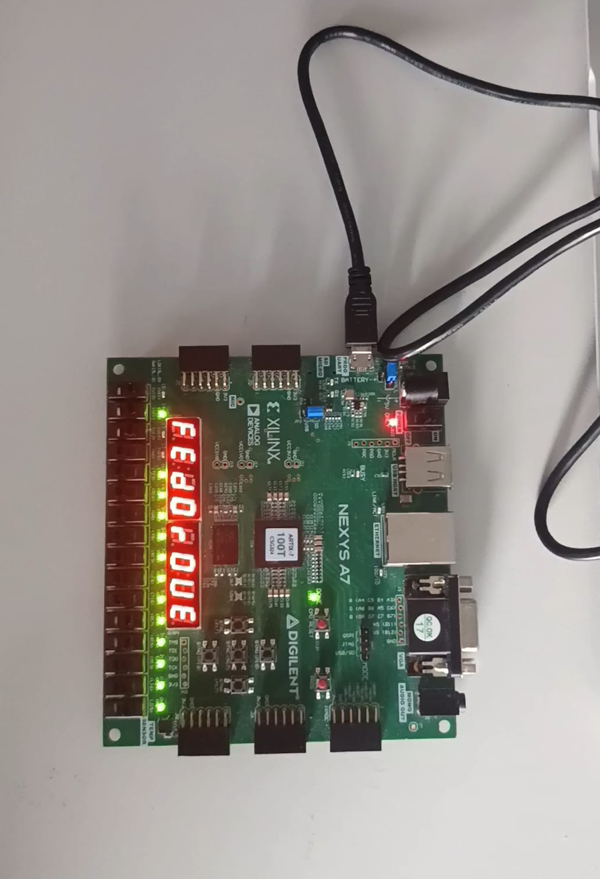
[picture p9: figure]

Fig. 8. Team C2 final working hardware demonstration on the Digilent Nexys A7 FPGA board.

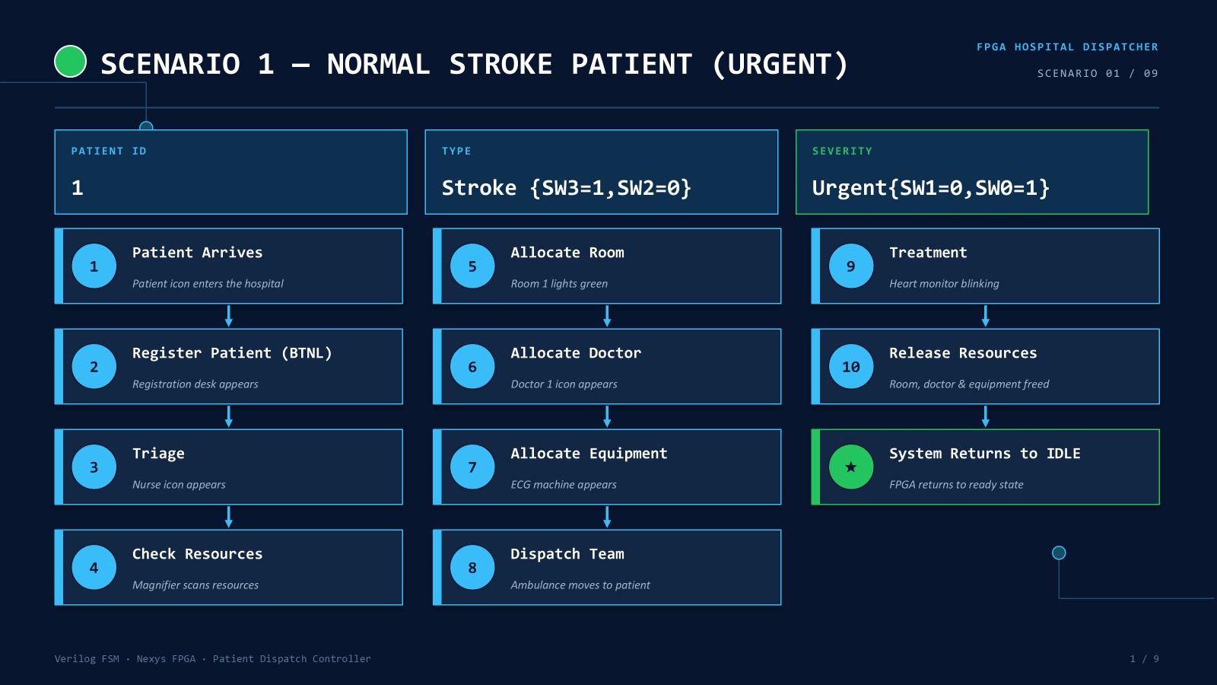
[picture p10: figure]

Fig. 9. Scenario 1: normal urgent-patient registration, allocation, treatment, release, and return to the idle state.

B. Critical Patient Handling

Figure 10 validates the critical-heart-attack path. The critical indication is asserted, the priority is raised to its highest level, resources are assigned, treatment duration is extended, and the flag is cleared after release.

C. Emergency Override

The emergency override sequence is shown in Fig. 11. A normal case can be escalated through the dedicated override control, forcing the critical path, activating the critical LED, and fast-tracking allocation and dispatch.

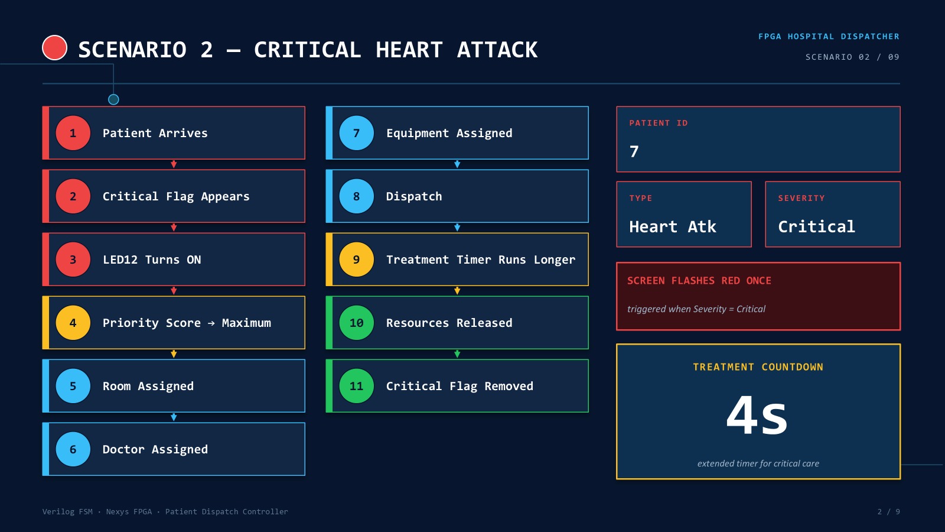
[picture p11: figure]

Fig. 10. Scenario 2: critical patient handling with maximum priority and extended treatment indication.

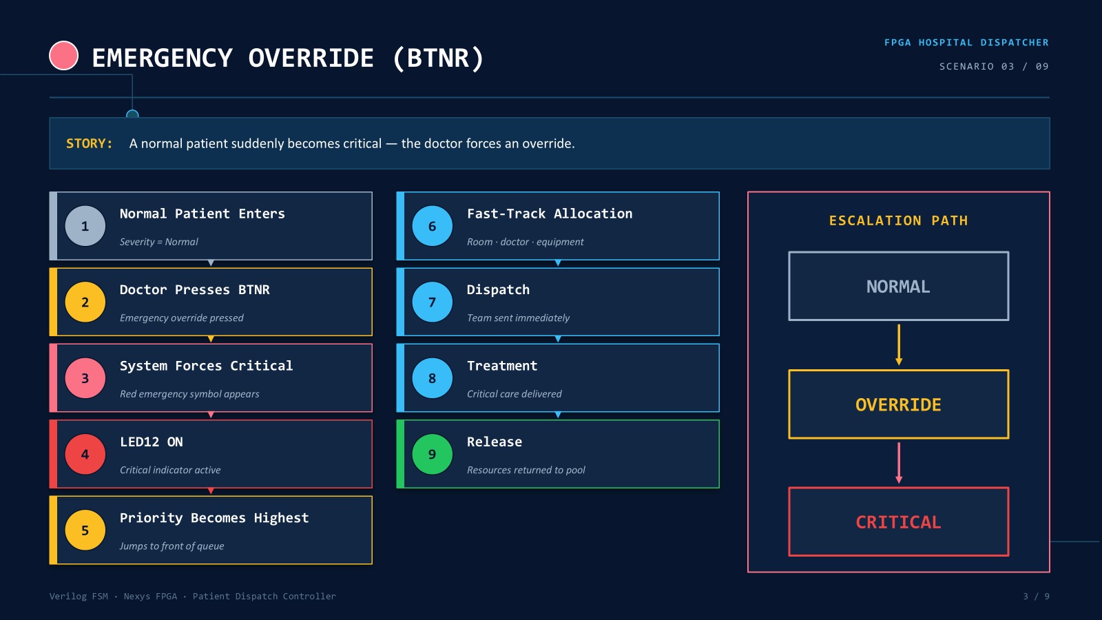
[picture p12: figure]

Fig. 11. Scenario 3: emergency override (BTNR) escalating a normal patient to the critical fast-track path.

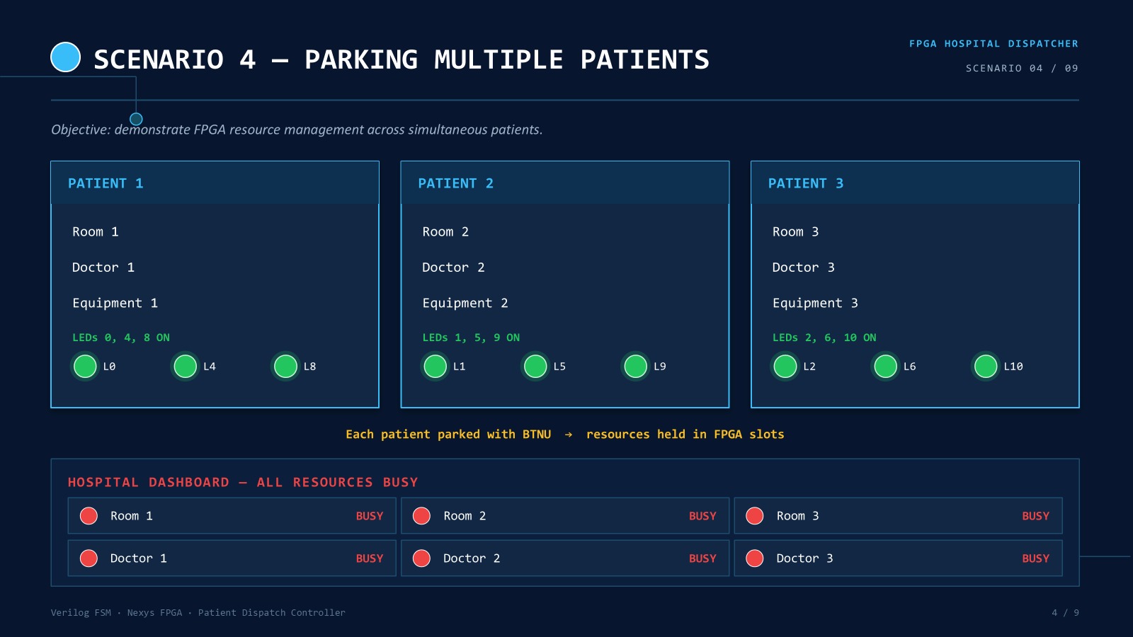
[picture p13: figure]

Fig. 12. Scenario 4: parking multiple patients while preserving their allocated resources in FPGA storage slots.

D. Multiple-Patient Parking
Figure 12 demonstrates retained allocations for multiple patients. Parking stores each assignment in the patient table and keeps the associated room, doctor, and equipment occupied until an explicit release is requested.
E. Selective Release
Figure 13 shows selective release. The operator chooses a stored slot, arms the release function, confirms it, and frees

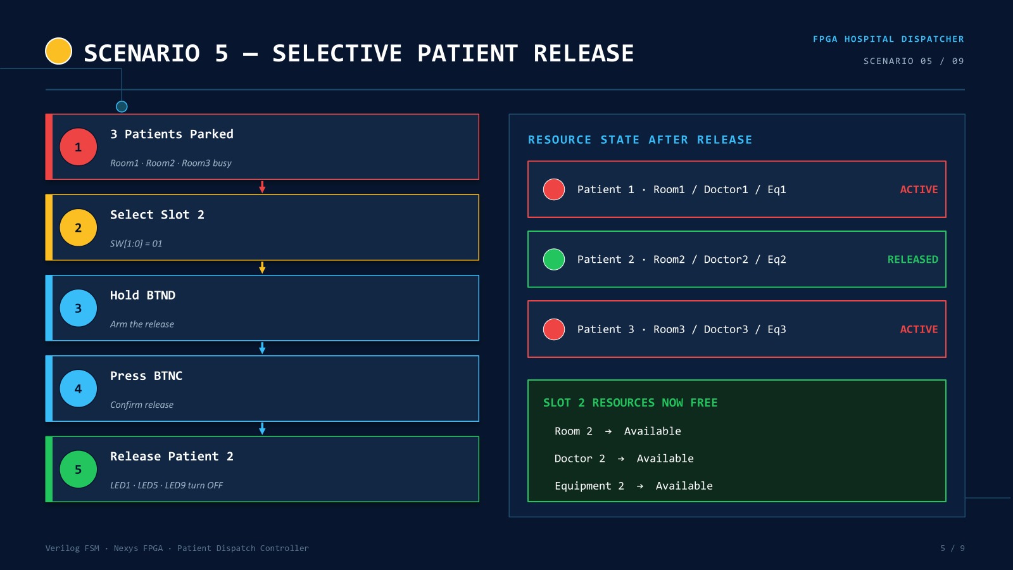
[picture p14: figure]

Fig. 13. Scenario 5: selective release of one parked patient without disturbing the remaining active allocations.

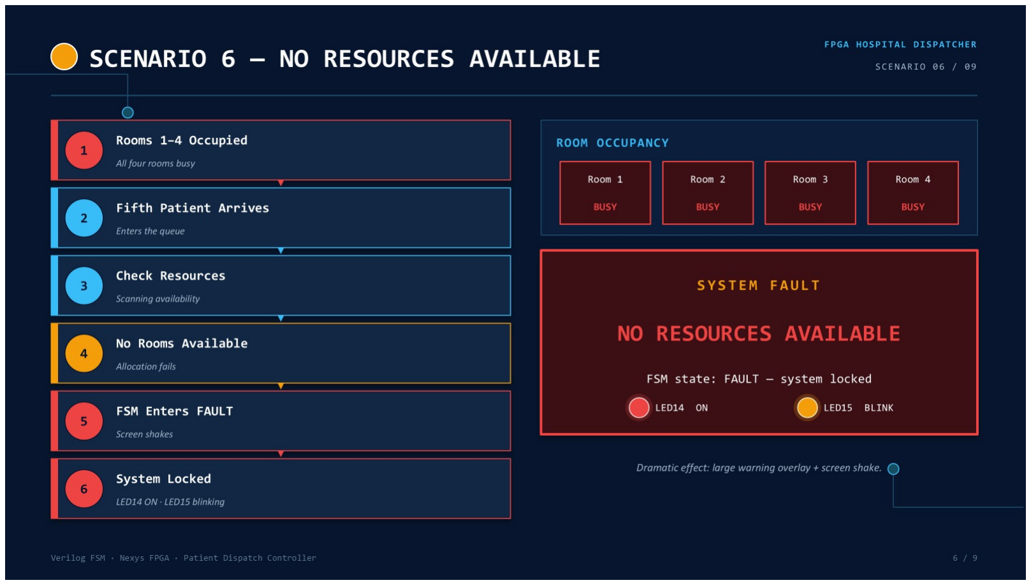
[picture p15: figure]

Fig. 14. Scenario 6: resource exhaustion causing controlled entry into the fault state and visible alarm indication.

only the room, doctor, and equipment belonging to the selected patient.

F. Resource Exhaustion
Figure 14 validates the no-resource condition. After all rooms are occupied, another admission cannot be allocated safely. The FSM enters the fault state, the system is locked, and the alarm indicators become active.
G. Full System Reset
Figure 15 documents recovery from the fault condition. Activating the reset clears state registers, occupancy, parked assignments, LEDs, and the latched alarm, restoring the ready state.
H. Hardware Resource Dashboard
Figure 16 summarizes the final occupancy and alert state. It displays room, doctor, and equipment status together with critical alerts and treatment information, providing an integrated view of the resource manager and scheduler outputs.

VI. RESULTS AND ENGINEERING ASSESSMENT
The project achieved its primary objectives. The RTL architecture is modular, each design unit has a corresponding testbench, the complete design was constrained and converted

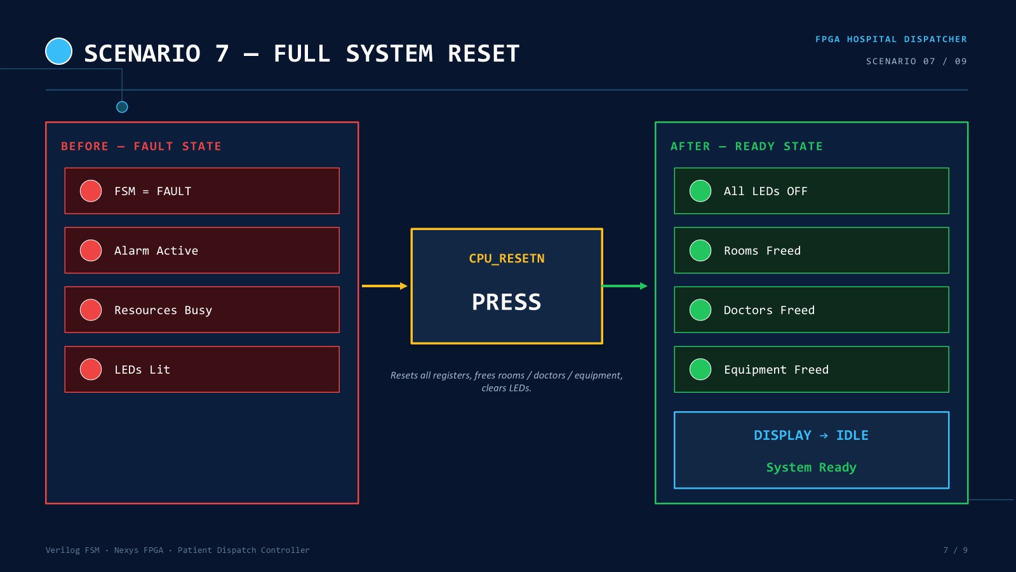
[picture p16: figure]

Fig. 15. Scenario 7: complete reset from the fault state to the ready/idle condition.

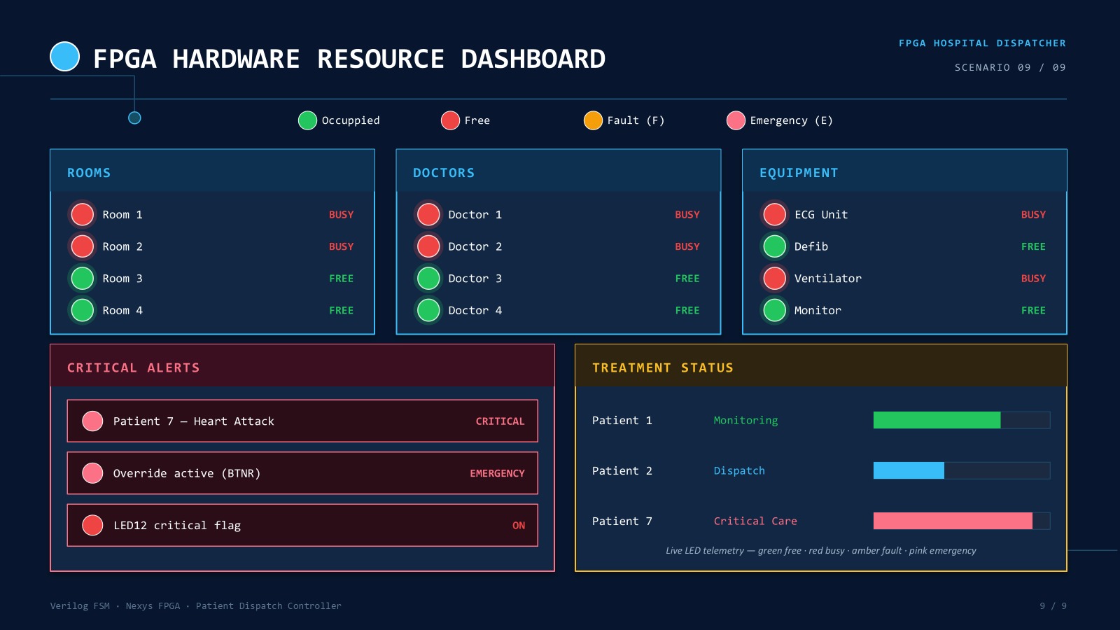
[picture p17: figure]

Fig. 16. FPGA hardware resource dashboard showing occupancy, availability, critical alerts, and treatment status.

into a board-programming bitstream, and the intended scenarios were demonstrated in the laboratory. The visual records show normal dispatch, critical handling, emergency override, multiple-patient parking, selective release, controlled resourceexhaustion behavior, reset recovery, and aggregate dashboard status.
The PCB work extends the project beyond an FPGA-only demonstration. The schematic sheets, routed board, three-dimensional model, bill of materials, Gerber set, and drill files form a manufacture-oriented design package. The assembled custom PCB was not part of the final laboratory evidence, so the report distinguishes the successfully demonstrated Nexys A7 implementation from the design-stage PCB realization. Several improvements are recommended for a productionoriented revision. Mechanical inputs should use explicit debounce logic; incoming patients could be queued instead of operating on one active transaction; safety requirements could be formalized as temporal properties; UART messages could include framing and integrity checks; and the PCB should undergo documented electrical-rule checking, designrule checking, regulator validation, connector pin review, and prototype bring-up. These items are refinements rather than changes to the fundamental architecture.

VII. CONCLUSION
Team C2 completed an end-to-end Smart Hospital Emergency Response Dispatcher integrating VHDL design, verification, FPGA deployment, laboratory demonstration, and Altium PCB engineering. The system comprises ten synthesizable modules and ten testbenches with 114 assertions. It supports triage, resource allocation, emergency escalation, patient parking, selective release, fault handling, visual indication, and serial reporting. The successful Nexys A7 demonstration confirms the interactive FPGA realization, while the schematics, PCB layout, three-dimensional model, bill of materials, and Gerber/drill outputs document the path toward dedicated hardware. Presenting every project figure individually provides clear and traceable evidence of the team’s technical achievements.

ACKNOWLEDGMENT
The authors thank the Hardware Engineering Laboratory teaching staff at Hochschule Hamm-Lippstadt for the laboratory platform, technical guidance, and opportunity to validate the design on physical FPGA hardware.

REFERENCES

[1] Digilent, Nexys A7 FPGA Board Reference Manual, 2024.
[2] AMD, Artix 7 FPGAs Data Sheet: DC and AC Switching Characteristics, 1st ed., Jul. 2024, product specification.
[3] IEEE, IEEE Standard for VHDL Language Reference Manual, 2019.
[4] ——, IEEE Standard Multivalue Logic System for VHDL Model Interoperability, 1993.
[5] AMD, Vivado Design Suite User Guide: Logic Simulation, 2024.
[6] ——, Vivado Design Suite User Guide: Synthesis, 2025.
[7] ——, Vivado Design Suite User Guide: Using Constraints, 2024.
[8] ——, Vivado Design Suite User Guide: Implementation, 2024.
[9] P. P. Chu, FPGA Prototyping by VHDL Examples: Xilinx MicroBlaze MCS SoC, 2nd ed. Wiley, 2017.
[10] M. M. Mano and M. D. Ciletti, Digital Design: With an Introduction to the Verilog HDL, VHDL, and SystemVerilog, 6th ed. Pearson, 2018.
[11] Altium, Altium Designer Documentation: Schematic Capture, PCB Layout, and Manufacturing Outputs, 2026.

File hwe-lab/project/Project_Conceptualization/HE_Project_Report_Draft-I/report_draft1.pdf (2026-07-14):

# Hardware Engineering Laboratory Final Report: FPGA-Based Smart Hospital Emergency Response Dispatcher

Team C2
Hardware Engineering Laboratory, 6th Semester Hochschule Hamm-Lippstadt, Germany Summer Semester 2026

Abstract—This report summarizes the complete Hardware Engineering Laboratory work completed by Team C2, from foundational combinational logic and arithmetic circuits to a modular Field-Programmable Gate Array (FPGA) system and a fabrication-ready custom printed circuit board. The final project, the Smart Hospital Emergency Response Dispatcher, was implemented in VHDL for the Digilent Nexys A7-100T. It receives patient data, calculates priority, allocates rooms, doctors and equipment, supervises unsafe conditions, and presents status through light-emitting diodes, an eight-digit seven-segment display and Universal Asynchronous Receiver-Transmitter communication. The repository contains ten synthesizable project modules, ten dedicated testbenches with 115 assertions, a board constraint file and a generated bitstream. The laboratory demonstration successfully exercised normal dispatch, critical-patient handling, parking of multiple patients, selective release, resource exhaustion, fault indication and full reset. In parallel, a seven-sheet Altium design, two-layer printed circuit board layout, 120-line bill of materials and complete Gerber/drill outputs were produced. The work demonstrates an end-to-end engineering workflow covering specification, digital design, verification, FPGA deployment, human-machine interfacing, safety logic and electronic design automation.
Index Terms—FPGA, VHDL, finite-state machine, resource management, functional safety, Altium Designer, printed circuit board, Nexys A7.
I. INTRODUCTION AND SCOPE
The laboratory was structured as a progressive hardwaredesign programme. Early exercises established correct use of concurrent and behavioural VHDL, hierarchical composition and self-checking testbenches. These foundations were extended to ripple-carry arithmetic, binary-coded-decimal conversion, seven-segment decoding, clock division and synchronous counters. The final project integrated these skills into a safety-oriented cyber-physical demonstrator representing the workflow of a hospital emergency department.
The principal engineering objective was not to implement a medical device, but to demonstrate deterministic hardware control: patient requests are encoded at the board inputs; triage information is latched; resources are allocated in a controlled sequence; invalid or unsafe situations trigger a fault; and the full state is made visible to an operator. The repository, design documentation, user manual, presentation and fabrication outputs were reviewed as the evidence base for this report [1]–[3].

TABLE I
SUMMARY OF LABORATORY ACHIEVEMENTS
Phase | Main implementation | Engineering outcome
Lab 1 | Gates, adders and subtractors | Boolean | and | behavioural
VHDL; basic testbenches
Lab 2 | Ripple-carry, | add/subtract,
| BCD adder, seven-segment decoder

Hierarchy, arithmetic datapaths and display encoding

Lab 4 Altium schematic and PCB ex- ercise

Electronic design automation and fabrication workflow
Lab 5 FPGA constraints and bit- streamsPhysical synthesis, pin mapping and board validation
Lab 7 Clock divider and decimal counters

Sequential logic, clock scaling and display control
Project | Hospital dispatcher system | Modular integration, safety su-
pervision and demonstration

II. LABORATORY PROGRESSION

A. Combinational Logic and Arithmetic
The first phase implemented an XOR gate, half and full adders, and half and full subtractors. These tasks established Boolean modelling, entity/architecture separation and waveform-based validation. The next phase introduced structural reuse through a full adder constructed from half adders, a ripple-carry adder, an adder/subtractor, a binary-codeddecimal adder and a binary-coded-decimal-to-seven-segment decoder. The exercises therefore moved from isolated truthtable functions to multi-bit datapaths and hierarchical design.
B. FPGA Deployment and Sequential Logic
The arithmetic design was subsequently paired with Nexys A7 constraint files and generated bitstreams, demonstrating the transition from simulation to physical input/output mapping. Later work implemented a clock divider, a one-digit decimal counter and a two-digit decimal counter. The one-digit counter uses the 100 MHz board clock, a start/stop switch, a clear button and an active-low seven-segment output. This phase addressed clock-domain timing, human-visible update rates, synchronous control and display multiplexing.

III. FINAL SYSTEM ARCHITECTURE
The final implementation is organised as ten synthesizable VHDL modules with clear functional boundaries. The


Fig. 1. Implemented dispatcher finite-state-machine workflow.

patient_generator captures patient identity, type and severity. The priority_encoder calculates triage priority. The resource_manager maintains four-bit occupancy vectors for rooms, doctors and equipment and selects the first available resource. The scheduler_fsm sequences the operational workflow. The patient_table stores parked patients and their assigned resources, while the safety_supervisor checks allocation and state consistency. Output handling is separated into LED, seven-segment and UART controllers, all connected by top_level.

The state machine in Fig. 1 implements IDLE, RECEIVE PATIENT, TRIAGE, CHECK RESOURCES, three allocation stages, DISPATCH TEAM, MONITOR TREATMENT, RE-LEASE RESOURCES and FAULT. Manual stepping makes each transition observable during demonstration, whereas the treatment state advances with a severity-dependent timer. A park command returns the controller to IDLE while retaining occupied resources, enabling up to four concurrent patient records. Selective release uses a two-bit slot index to free the room, doctor and equipment associated with one parked patient.

Priority is formed from a severity base value and a typerelated boost. Critical patients therefore receive the highest scheduling significance, and an emergency-override input can force escalation. The design maps room, doctor and equipment occupancy to twelve LEDs; separate LEDs indicate critical status, active treatment, system fault and a latched blinking alarm. The eight-digit display presents patient identity, severity, room, doctor, emergency indication and finite-state-machine code [2].

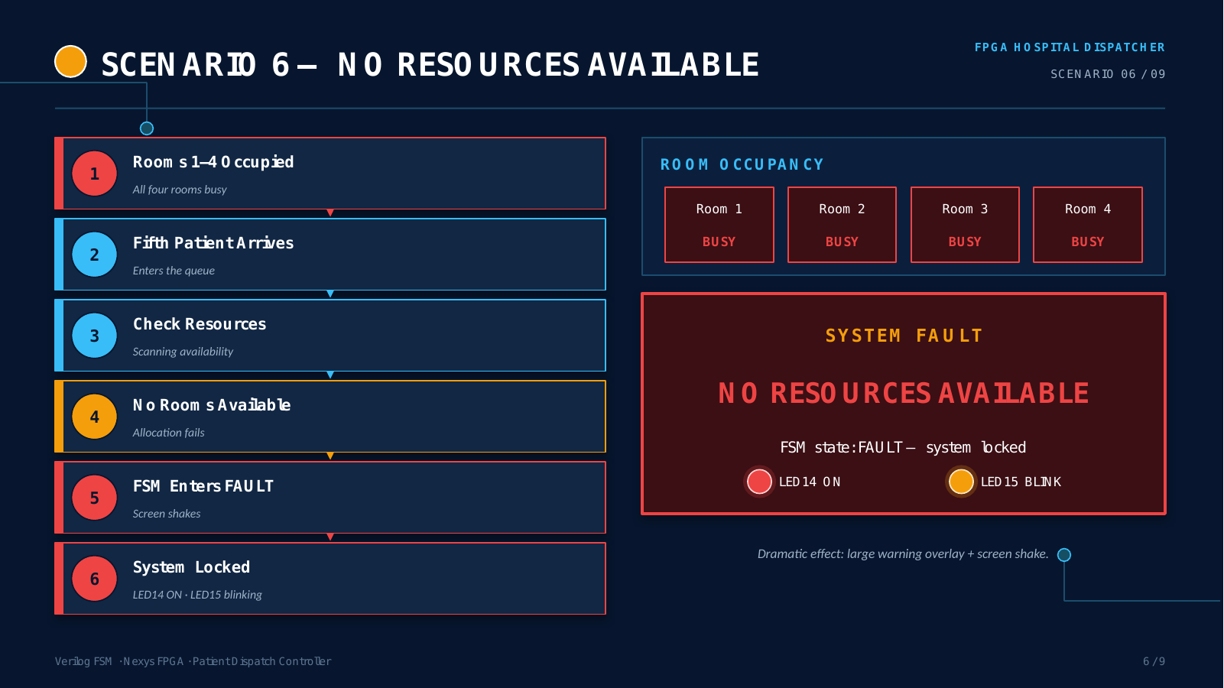
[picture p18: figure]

Fig. 2. Demonstration scenario for complete room occupancy and transition to FAULT.

IV. SAFETY AND DETERMINISTIC RESOURCE CONTROL
Safety behaviour was implemented directly in hardware rather than added only as a display feature. The supervisor detects an allocation request when the relevant resource class is already full, resource exhaustion during allocation and invalid state encodings. The immediate fault output can clear after the initiating condition disappears, but the alarm is latched until reset. The scheduler also enters FAULT when required resources are unavailable, preventing uncontrolled continuation. The resource manager uses explicit occupancy registers and deterministic first-free selection. Allocation and release are issued as single-cycle control strobes. This creates an auditable transaction model: one controller requests an operation, one manager updates occupancy, and the safety supervisor independently observes the request and current capacity. The patient table has priority over normal finite-state-machine release indices when a parked patient is selectively released, avoiding simultaneous conflicting release paths.
V. VERIFICATION AND LABORATORY DEMONSTRATION
The project includes a dedicated testbench for every synthesizable module. Together, the ten project testbenches contain 115 explicit assertions. They check priority values, patient capture, allocation and release, patient-table storage, state transitions, fault latching, display encodings, UART frame transmission and top-level integration. The integration test covers a complete dispatch-and-release cycle, parking with resources retained, and selective release of a stored patient. The final bitstream and Nexys A7 constraint file provide implementation evidence beyond behavioural source code. During the laboratory demonstration, the board operated successfully and the team demonstrated the scenarios summarized in Table II. The result confirms that switch/button inputs, finite-state-machine stepping, occupancy LEDs, seven-segment status and safety responses functioned coherently on physical hardware.

VI. ALTIUM SCHEMATIC AND PCB DESIGN
A custom interface board was designed in Altium Designer Professional 26.7.1 to support the dispatcher concept. The

TABLE II
SUCCESSFUL DEMONSTRATION COVERAGE
Scenario | Observed system behaviour
Normal urgent patient | Full register, triage, allocate, dispatch, monitor
| and release sequence
Critical heart attack | Critical indicator, maximum priority and ex-
| tended treatment interval
Emergency override | Input escalation to critical handling
Multiple patients | Parked records retained with independent re-
| source occupancy
Selective release | Chosen patient slot released without disturbing
| other occupied slots
No resources | FAULT state, fault LED and blinking latched
| alarm
Full reset | Registers, resources, alarms and displays returned
| to ready state

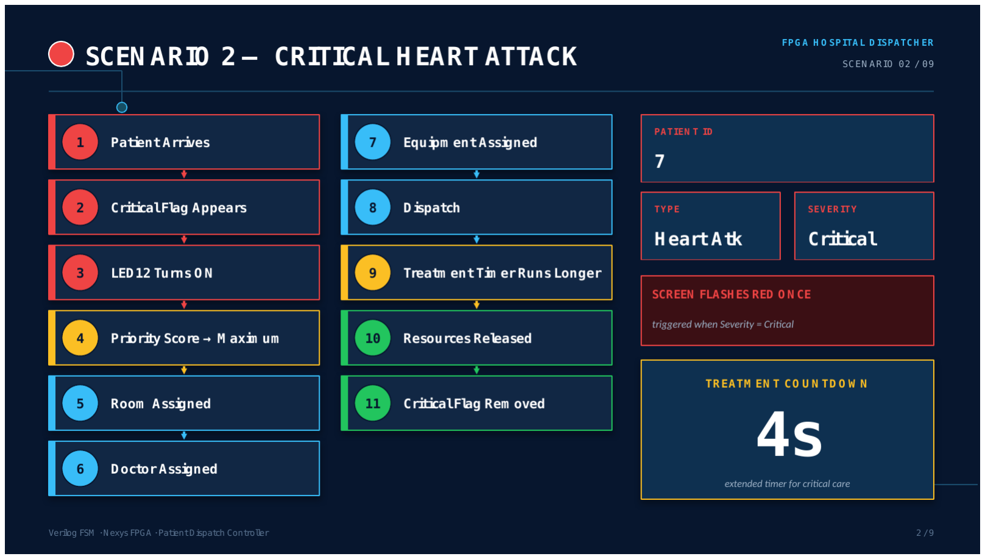
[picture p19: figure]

Fig. 3. Critical-patient scenario used to communicate and demonstrate system behaviour.

design is split into seven schematic sheets: power, FPGA interface/core, clock/configuration/JTAG, inputs, LED outputs, four dual-digit seven-segment displays, and buzzer/UART. This sheet partitioning improves reviewability and supports independent checking of power, control and human-machineinterface functions [4].

The board accepts 5 V input and includes 3.3 V, 1.8 V and 1.0 V regulator stages with local decoupling. A custom 56-pin connector interfaces to the Nexys A7. Operator controls comprise eight slide switches and six push buttons for reset, new patient, step, override, release and park. Outputs include sixteen LEDs, four dual-digit displays and a magnetic buzzer. UART and JTAG headers provide communication and programming access.

The printed circuit board is a two-layer mixed throughhole/surface-mount design. The bill of materials contains 120 populated designator lines representing 20 unique component descriptions. Manufacturing outputs include top and bottom copper, solder mask, paste and legend layers, board profile, plated-through-hole and non-plated-through-hole drill data, an aperture file and the bill of materials [5], [6]. This is a complete fabrication handoff rather than only a schematic concept.

VII. ENGINEERING ASSESSMENT

The strongest outcome is the continuity of the workflow. The team did not stop at an algorithmic finite-state-machine model: the work connects specification, VHDL decomposition, module-level and integration-level verification, constraint mapping, bitstream generation, physical demonstration, user documentation, schematic capture, printed circuit board layout and fabrication files. Functional concerns were also separated appropriately. Scheduling, resource accounting, patient storage, safety monitoring and user-interface encoding are independent modules, reducing coupling and making faults easier to localize. The evidence also supports several quality observations. First, the project uses self-checking testbenches rather than relying only on waveform inspection. Second, fault and alarm behaviour is intentionally different: fault reflects the present condition, whereas alarm memory requires operator reset. Third, resource assignment is deterministic, which makes demonstrations repeatable. Fourth, the manual defines exact switch settings, button sequences and expected display/LED results, enabling reproducible acceptance testing.
Remaining engineering work is mainly associated with productisation. The Altium board should undergo a formal electrical-rule/design-rule review, power-budget and thermal calculation, connector pin-by-pin verification against the Nexys A7 electrical limits, signal-integrity review and manufacturedboard bring-up. For the FPGA design, useful extensions would include automated synthesis/timing reports under version control, constrained-random or coverage-driven verification, debounce timing characterization, UART receive commands and persistent logging. These are logical next steps and do not diminish the achieved laboratory objective.

VIII. CONCLUSION

Team C2 completed a broad and coherent Hardware Engineering Laboratory portfolio. The work progressed from elementary combinational circuits to arithmetic subsystems, FPGA-mapped counters and a modular emergency-dispatch controller. The final system contains ten VHDL modules, ten self-checking testbenches, 115 assertions, a Nexys A7 bitstream and a successful physical demonstration covering normal, critical, multi-patient and fault scenarios. The accompanying Altium package adds seven schematic sheets, a routed two-layer printed circuit board, a 120-line bill of materials and full manufacturing data. Collectively, these deliverables demonstrate technical competence in digital logic, synchronous design, verification, FPGA implementation, safety-oriented control, human-machine interfacing and printed circuit board engineering.

REFERENCES

[1] Team C2, “SS2026 HWE Laboratory Repository,” VHDL sources, testbenches, constraints and bitstreams, HSHL, 2026.
[2] Team C2, “FPGA-Based Smart Hospital Emergency Response Dispatcher: User Manual,” 2026.
[3] Team C2, “FPGA-Based Smart Hospital Emergency Response Dispatcher Using the Digilent Nexys A7,” project conceptualization document, 2026.
[4] Team C2, “Smart Hospital Dispatcher Schematics,” seven-sheet Altium schematic export, rev. 1, June 2026.

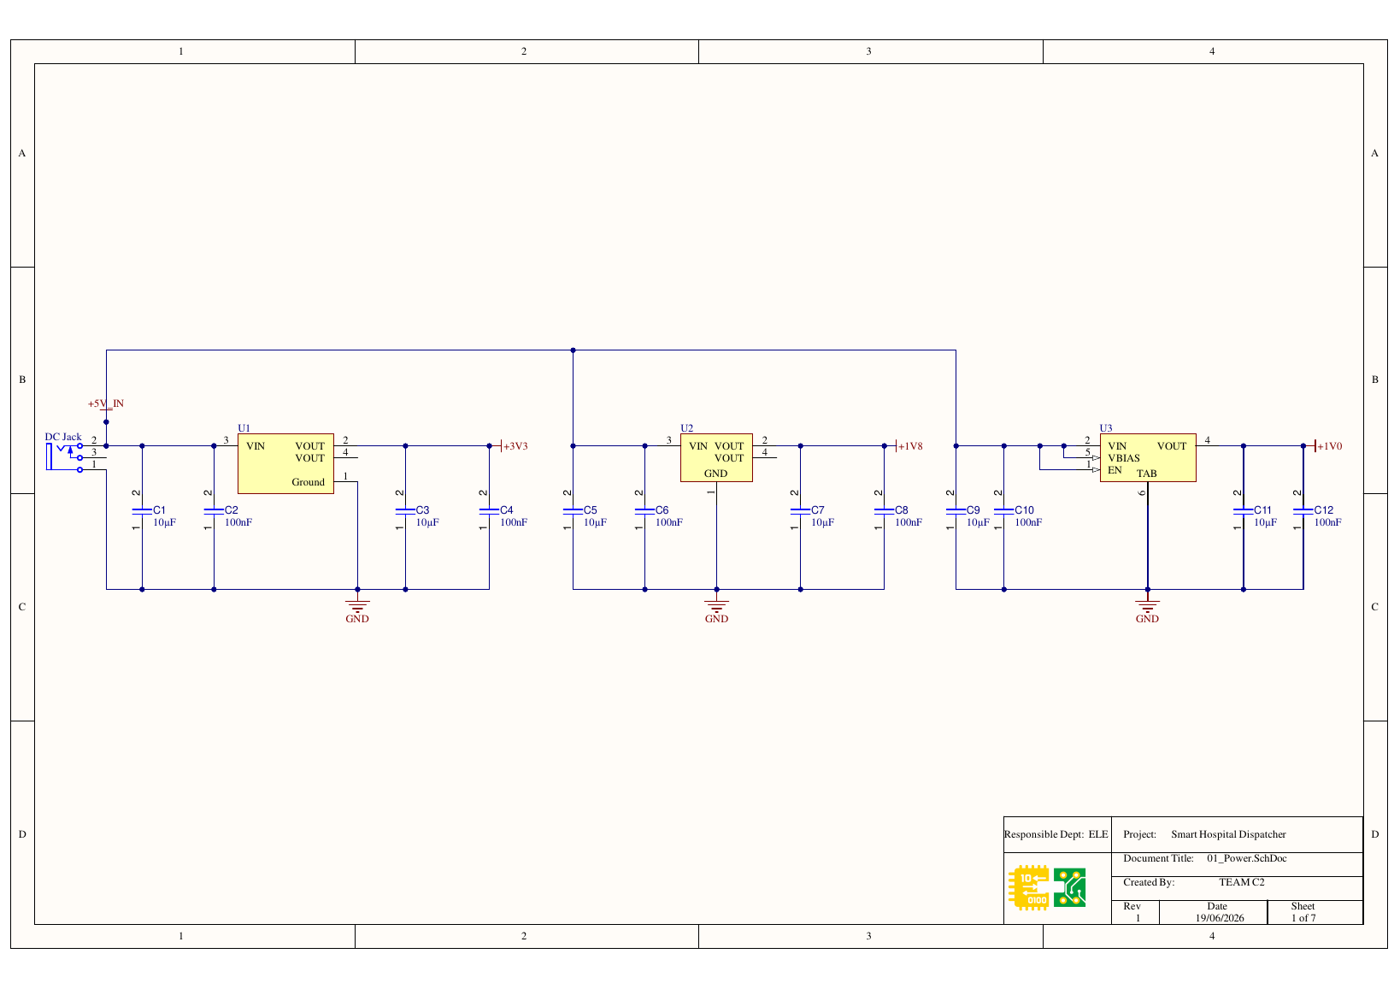
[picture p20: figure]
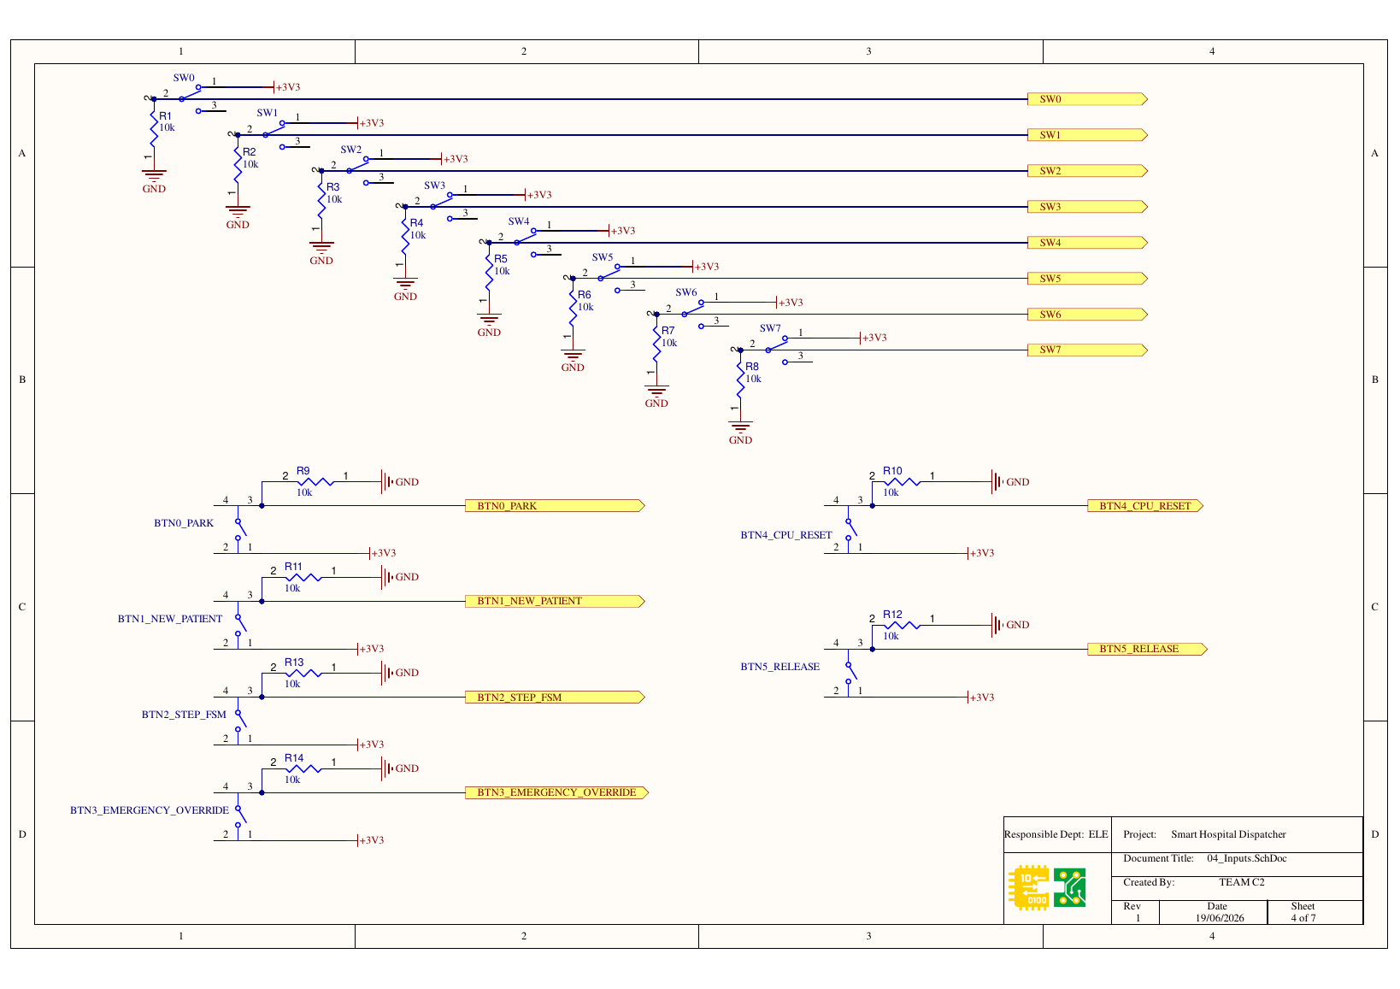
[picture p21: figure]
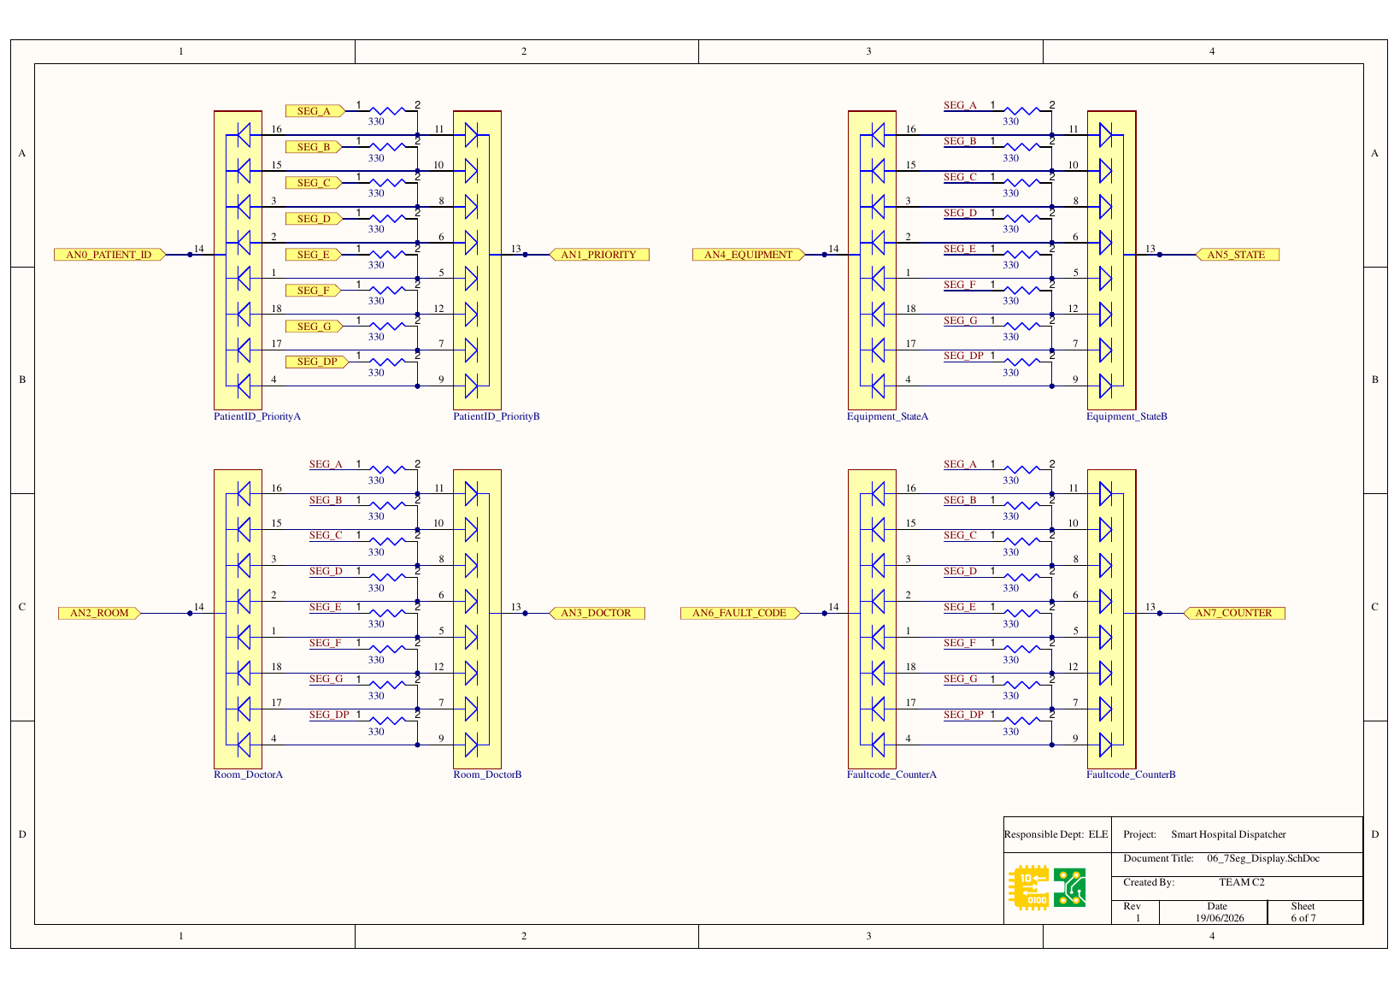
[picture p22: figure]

(a) Multi-rail power section | (b) Switch and push-button inputs | (c) Seven-segment display interfaces
Fig. 4. Selected sheets from the seven-sheet Altium schematic package.


Fig. 5. Altium three-dimensional rendering of the Smart Hospital Dispatcher interface PCB.

[5] Team C2, “Smart Hospital Dispatcher PCB Layout and Gerber Fabrication Package,” 2026.
[6] Team C2, “Smart Hospital Dispatcher Bill of Materials,” Altium BOM export, 2026.

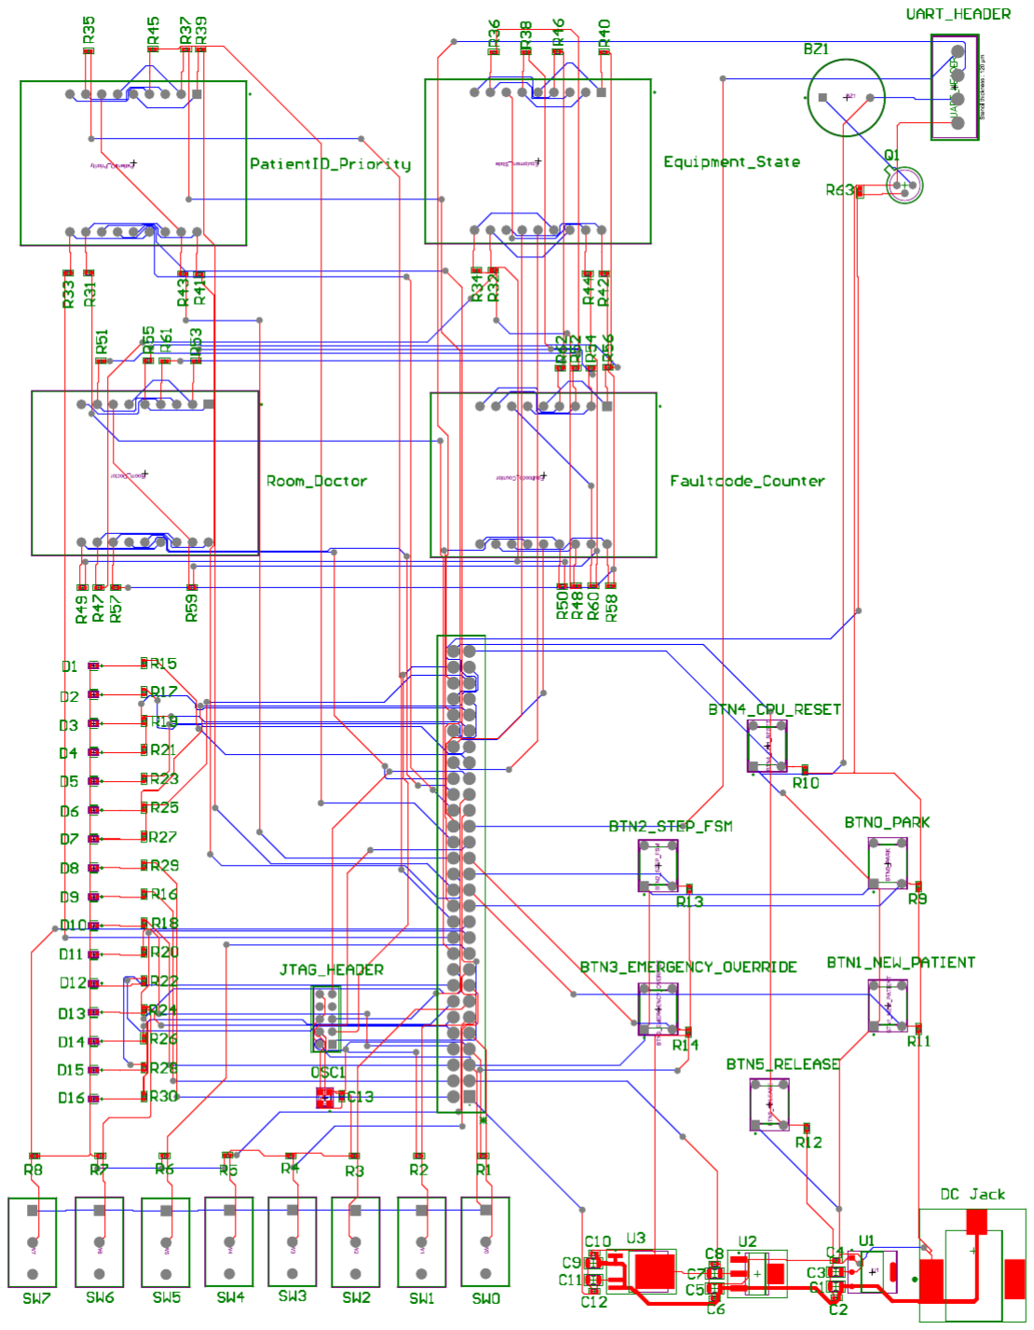
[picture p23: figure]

Fig. 6. Routed two-layer PCB layout and component placement.

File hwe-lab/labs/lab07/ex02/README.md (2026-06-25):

What we implemented:

Top module name:

One_Digit_Counter

Inputs:

CLK100MHZ
START_STOP
CLEAR

Outputs:

CA, CB, CC, CD, CE, CF, CG, DP
AN

Board connection used

Function        Nexys A7 input
Start / Stop   SW0
Clear / Reset  BTNC
Display        One digit of onboard 7-segment display
Clock          100 MHz onboard clock

Important notes

The VHDL uses only standard VHDL types:

bit
bit_vector
integer

No std_logic, no std_logic_vector, and no IEEE std_logic_1164 library are used.

The counter counts:

0 -> 1 -> 2 -> 3 -> 4 -> 5 -> 6 -> 7 -> 8 -> 9 -> 0

When:

START_STOP = 1

the counter runs.

When:

START_STOP = 0

the counter pauses.

When:

CLEAR = 1

the counter resets to zero.

The display is active-low, as required for the Nexys A7 7-segment display.

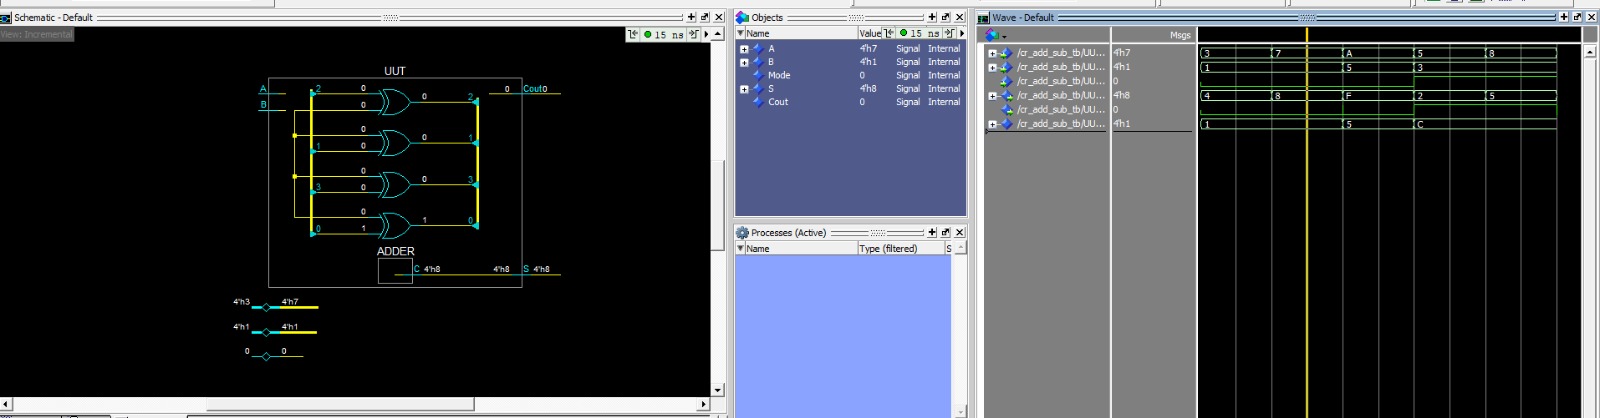
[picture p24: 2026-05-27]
hwe-lab/labs/lab02/ex03/tb_schematic/Schematic.jpeg

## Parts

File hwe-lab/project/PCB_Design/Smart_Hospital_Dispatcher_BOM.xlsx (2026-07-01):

Name | Description | Designator | Footprint | LibRef | Quantity | Manufacturer
MJTP1230A | SWITCH TACTILE SPST-NO 0.05A 12V | BTN0_PARK | FP-MJTP1230A-MFG | CMP-47024-000004-1 | 1
MJTP1230A | SWITCH TACTILE SPST-NO 0.05A 12V | BTN1_NEW_PATIENT | FP-MJTP1230A-MFG | CMP-47024-000004-1 | 1
MJTP1230A | SWITCH TACTILE SPST-NO 0.05A 12V | BTN2_STEP_FSM | FP-MJTP1230A-MFG | CMP-47024-000004-1 | 1
MJTP1230A | SWITCH TACTILE SPST-NO 0.05A 12V | BTN3_EMERGENCY_OVERRIDE | FP-MJTP1230A-MFG | CMP-47024-000004-1 | 1
MJTP1230A | SWITCH TACTILE SPST-NO 0.05A 12V | BTN4_CPU_RESET | FP-MJTP1230A-MFG | CMP-47024-000004-1 | 1
MJTP1230A | SWITCH TACTILE SPST-NO 0.05A 12V | BTN5_RELEASE | FP-MJTP1230A-MFG | CMP-47024-000004-1 | 1
AI-1223-TWT-3V-2-R | BUZZER MAGNETIC 3V 12MM TH | BZ1 | FP-AI-1223-TWT-3V-2-R-MFG | CMP-103888-000003-1 | 1
Capacitor 10µF +/-20% 25V 0805 | Chip Capacitor, 10µF +/-20%, 25V, 0805, Thickness 1.45 mm | C1 | CAPC0805(2012)145_L | CMP-001-00079-4 | 1
Capacitor 100nF +/-20% 10V 0402 | Chip Capacitor, 100nF +/-20%, 10V, 0402, Thickness 0.6 mm | C2 | CAPC0402(1005)60_L | CMP-001-00061-3 | 1
Capacitor 10µF +/-20% 25V 0805 | Chip Capacitor, 10µF +/-20%, 25V, 0805, Thickness 1.45 mm | C3 | CAPC0805(2012)145_L | CMP-001-00079-4 | 1
Capacitor 100nF +/-20% 10V 0402 | Chip Capacitor, 100nF +/-20%, 10V, 0402, Thickness 0.6 mm | C4 | CAPC0402(1005)60_L | CMP-001-00061-3 | 1
Capacitor 10µF +/-20% 25V 0805 | Chip Capacitor, 10µF +/-20%, 25V, 0805, Thickness 1.45 mm | C5 | CAPC0805(2012)145_L | CMP-001-00079-4 | 1
Capacitor 100nF +/-20% 10V 0402 | Chip Capacitor, 100nF +/-20%, 10V, 0402, Thickness 0.6 mm | C6 | CAPC0402(1005)60_L | CMP-001-00061-3 | 1
Capacitor 10µF +/-20% 25V 0805 | Chip Capacitor, 10µF +/-20%, 25V, 0805, Thickness 1.45 mm | C7 | CAPC0805(2012)145_L | CMP-001-00079-4 | 1
Capacitor 100nF +/-20% 10V 0402 | Chip Capacitor, 100nF +/-20%, 10V, 0402, Thickness 0.6 mm | C8 | CAPC0402(1005)60_L | CMP-001-00061-3 | 1
Capacitor 10µF +/-20% 25V 0805 | Chip Capacitor, 10µF +/-20%, 25V, 0805, Thickness 1.45 mm | C9 | CAPC0805(2012)145_L | CMP-001-00079-4 | 1
Capacitor 100nF +/-20% 10V 0402 | Chip Capacitor, 100nF +/-20%, 10V, 0402, Thickness 0.6 mm | C10 | CAPC0402(1005)60_L | CMP-001-00061-3 | 1
Capacitor 10µF +/-20% 25V 0805 | Chip Capacitor, 10µF +/-20%, 25V, 0805, Thickness 1.45 mm | C11 | CAPC0805(2012)145_L | CMP-001-00079-4 | 1
Capacitor 100nF +/-20% 10V 0402 | Chip Capacitor, 100nF +/-20%, 10V, 0402, Thickness 0.6 mm | C12 | CAPC0402(1005)60_L | CMP-001-00061-3 | 1
Capacitor 100nF +/-20% 50V 0402 | Chip Capacitor, 100nF +/-20%, 50V, 0402, Thickness 0.6 mm | C13 | CAPC0402(1005)60_L | CMP-001-00067-3 | 1
SM0402GC | LED GREEN CLEAR 0402 SMD | D1 | FP-SM0402GC-MFG | CMP-35283-000001-2 | 1
SM0402GC | LED GREEN CLEAR 0402 SMD | D2 | FP-SM0402GC-MFG | CMP-35283-000001-2 | 1
SM0402GC | LED GREEN CLEAR 0402 SMD | D3 | FP-SM0402GC-MFG | CMP-35283-000001-2 | 1
SM0402GC | LED GREEN CLEAR 0402 SMD | D4 | FP-SM0402GC-MFG | CMP-35283-000001-2 | 1
SM0402GC | LED GREEN CLEAR 0402 SMD | D5 | FP-SM0402GC-MFG | CMP-35283-000001-2 | 1
SM0402GC | LED GREEN CLEAR 0402 SMD | D6 | FP-SM0402GC-MFG | CMP-35283-000001-2 | 1
SM0402GC | LED GREEN CLEAR 0402 SMD | D7 | FP-SM0402GC-MFG | CMP-35283-000001-2 | 1
SM0402GC | LED GREEN CLEAR 0402 SMD | D8 | FP-SM0402GC-MFG | CMP-35283-000001-2 | 1
SM0402GC | LED GREEN CLEAR 0402 SMD | D9 | FP-SM0402GC-MFG | CMP-35283-000001-2 | 1
SM0402GC | LED GREEN CLEAR 0402 SMD | D10 | FP-SM0402GC-MFG | CMP-35283-000001-2 | 1
SM0402GC | LED GREEN CLEAR 0402 SMD | D11 | FP-SM0402GC-MFG | CMP-35283-000001-2 | 1
SM0402GC | LED GREEN CLEAR 0402 SMD | D12 | FP-SM0402GC-MFG | CMP-35283-000001-2 | 1
SM0402GC | LED GREEN CLEAR 0402 SMD | D13 | FP-SM0402GC-MFG | CMP-35283-000001-2 | 1
SM0402GC | LED GREEN CLEAR 0402 SMD | D14 | FP-SM0402GC-MFG | CMP-35283-000001-2 | 1
SM0402GC | LED GREEN CLEAR 0402 SMD | D15 | FP-SM0402GC-MFG | CMP-35283-000001-2 | 1
SM0402GC | LED GREEN CLEAR 0402 SMD | D16 | FP-SM0402GC-MFG | CMP-35283-000001-2 | 1
RASM722X | Power Jack, 5 A, 250 V, 3-Pin SMD, RoHS, Bulk | DC Jack | SWIT-RASM722X_V | CMP-002-00013-2 | 1 | Switchcraft
DC08-11SRWA | DISPLAY 660NM RED 2DIG 0.8" 7SEG | Equipment_State | FP-DC08-11SRWA-MFG | CMP-44525-000001-1 | 1 | Kingbright
DC08-11SRWA | DISPLAY 660NM RED 2DIG 0.8" 7SEG | Faultcode_Counter | FP-DC08-11SRWA-MFG | CMP-44525-000001-1 | 1 | Kingbright
FPGA Interface Header | Custom 58-Pin FPGA Interface Connector (2×29 Through-Hole) for Nexys A7-100T | J1 | FPGA_IF_2*29_TH | XC7A100T_CUSTOM | 1
TW-05-03-F-D-378-078 | Through-Hole Board Stacker, Vertical, -55 to 125 degC, 2 mm Pitch, 10-Pin, Male, RoHS | JTAG_HEADER | SMTC-TW-05-03-X-D-378-078 | CMP-1029-00381-1 | 1 | Samtec
SIT8008BI-11-33N-100.000000 | 100.00000 MHz XO (Standard) HCMOS, LVCMOS Oscillator 3.3V No Connect 4-SMD, No Lead | OSC1 | FP-SIT8008-1-MFG | CMP-25159-140056-1 | 1 | SiTime
DC08-11SRWA | DISPLAY 660NM RED 2DIG 0.8" 7SEG | PatientID_Priority | FP-DC08-11SRWA-MFG | CMP-44525-000001-1 | 1 | Kingbright
2N2222A | High Speed Switch, 0.6 A IC, -65 to 175 degC, 3-Pin TO-18, RoHS, Bulk | Q1 | STM-TO-18-3 | CMP-2000-05381-1 | 1 | STMicroelectronics
Resistor 10K +/-1 % 0402 63 mW | Chip Resistor, 10 kOhms, +/-1 %, 63 mW, -55 to 125 degC, 0402 | R1 | RESC0402(1005)_L | CMP-009-00149-3 | 1
Resistor 10K +/-1 % 0402 63 mW | Chip Resistor, 10 kOhms, +/-1 %, 63 mW, -55 to 125 degC, 0402 | R2 | RESC0402(1005)_L | CMP-009-00149-3 | 1
Resistor 10K +/-1 % 0402 63 mW | Chip Resistor, 10 kOhms, +/-1 %, 63 mW, -55 to 125 degC, 0402 | R3 | RESC0402(1005)_L | CMP-009-00149-3 | 1
Resistor 10K +/-1 % 0402 63 mW | Chip Resistor, 10 kOhms, +/-1 %, 63 mW, -55 to 125 degC, 0402 | R4 | RESC0402(1005)_L | CMP-009-00149-3 | 1
Resistor 10K +/-1 % 0402 63 mW | Chip Resistor, 10 kOhms, +/-1 %, 63 mW, -55 to 125 degC, 0402 | R5 | RESC0402(1005)_L | CMP-009-00149-3 | 1
Resistor 10K +/-1 % 0402 63 mW | Chip Resistor, 10 kOhms, +/-1 %, 63 mW, -55 to 125 degC, 0402 | R6 | RESC0402(1005)_L | CMP-009-00149-3 | 1
Resistor 10K +/-1 % 0402 63 mW | Chip Resistor, 10 kOhms, +/-1 %, 63 mW, -55 to 125 degC, 0402 | R7 | RESC0402(1005)_L | CMP-009-00149-3 | 1
Resistor 10K +/-1 % 0402 63 mW | Chip Resistor, 10 kOhms, +/-1 %, 63 mW, -55 to 125 degC, 0402 | R8 | RESC0402(1005)_L | CMP-009-00149-3 | 1
Resistor 10K +/-1 % 0402 63 mW | Chip Resistor, 10 kOhms, +/-1 %, 63 mW, -55 to 125 degC, 0402 | R9 | RESC0402(1005)_L | CMP-009-00149-3 | 1
Resistor 10K +/-1 % 0402 63 mW | Chip Resistor, 10 kOhms, +/-1 %, 63 mW, -55 to 125 degC, 0402 | R10 | RESC0402(1005)_L | CMP-009-00149-3 | 1
Resistor 10K +/-1 % 0402 63 mW | Chip Resistor, 10 kOhms, +/-1 %, 63 mW, -55 to 125 degC, 0402 | R11 | RESC0402(1005)_L | CMP-009-00149-3 | 1
Resistor 10K +/-1 % 0402 63 mW | Chip Resistor, 10 kOhms, +/-1 %, 63 mW, -55 to 125 degC, 0402 | R12 | RESC0402(1005)_L | CMP-009-00149-3 | 1
Resistor 10K +/-1 % 0402 63 mW | Chip Resistor, 10 kOhms, +/-1 %, 63 mW, -55 to 125 degC, 0402 | R13 | RESC0402(1005)_L | CMP-009-00149-3 | 1
Resistor 10K +/-1 % 0402 63 mW | Chip Resistor, 10 kOhms, +/-1 %, 63 mW, -55 to 125 degC, 0402 | R14 | RESC0402(1005)_L | CMP-009-00149-3 | 1
330R2J | 330R 0.063W 5% 0402 (1005 Metric) SMD | R15 | RESC0402(1005)_L | CMP-009-00095-2 | 1
330R2J | 330R 0.063W 5% 0402 (1005 Metric) SMD | R16 | RESC0402(1005)_L | CMP-009-00095-2 | 1
330R2J | 330R 0.063W 5% 0402 (1005 Metric) SMD | R17 | RESC0402(1005)_L | CMP-009-00095-2 | 1
330R2J | 330R 0.063W 5% 0402 (1005 Metric) SMD | R18 | RESC0402(1005)_L | CMP-009-00095-2 | 1
330R2J | 330R 0.063W 5% 0402 (1005 Metric) SMD | R19 | RESC0402(1005)_L | CMP-009-00095-2 | 1
330R2J | 330R 0.063W 5% 0402 (1005 Metric) SMD | R20 | RESC0402(1005)_L | CMP-009-00095-2 | 1
330R2J | 330R 0.063W 5% 0402 (1005 Metric) SMD | R21 | RESC0402(1005)_L | CMP-009-00095-2 | 1
330R2J | 330R 0.063W 5% 0402 (1005 Metric) SMD | R22 | RESC0402(1005)_L | CMP-009-00095-2 | 1
330R2J | 330R 0.063W 5% 0402 (1005 Metric) SMD | R23 | RESC0402(1005)_L | CMP-009-00095-2 | 1
330R2J | 330R 0.063W 5% 0402 (1005 Metric) SMD | R24 | RESC0402(1005)_L | CMP-009-00095-2 | 1
330R2J | 330R 0.063W 5% 0402 (1005 Metric) SMD | R25 | RESC0402(1005)_L | CMP-009-00095-2 | 1
330R2J | 330R 0.063W 5% 0402 (1005 Metric) SMD | R26 | RESC0402(1005)_L | CMP-009-00095-2 | 1
330R2J | 330R 0.063W 5% 0402 (1005 Metric) SMD | R27 | RESC0402(1005)_L | CMP-009-00095-2 | 1
330R2J | 330R 0.063W 5% 0402 (1005 Metric) SMD | R28 | RESC0402(1005)_L | CMP-009-00095-2 | 1
330R2J | 330R 0.063W 5% 0402 (1005 Metric) SMD | R29 | RESC0402(1005)_L | CMP-009-00095-2 | 1
330R2J | 330R 0.063W 5% 0402 (1005 Metric) SMD | R30 | RESC0402(1005)_L | CMP-009-00095-2 | 1
330R2J | 330R 0.063W 5% 0402 (1005 Metric) SMD | R31 | RESC0402(1005)_L | CMP-009-00095-2 | 1
330R2J | 330R 0.063W 5% 0402 (1005 Metric) SMD | R32 | RESC0402(1005)_L | CMP-009-00095-2 | 1
330R2J | 330R 0.063W 5% 0402 (1005 Metric) SMD | R33 | RESC0402(1005)_L | CMP-009-00095-2 | 1
330R2J | 330R 0.063W 5% 0402 (1005 Metric) SMD | R34 | RESC0402(1005)_L | CMP-009-00095-2 | 1
330R2J | 330R 0.063W 5% 0402 (1005 Metric) SMD | R35 | RESC0402(1005)_L | CMP-009-00095-2 | 1
330R2J | 330R 0.063W 5% 0402 (1005 Metric) SMD | R36 | RESC0402(1005)_L | CMP-009-00095-2 | 1
330R2J | 330R 0.063W 5% 0402 (1005 Metric) SMD | R37 | RESC0402(1005)_L | CMP-009-00095-2 | 1
330R2J | 330R 0.063W 5% 0402 (1005 Metric) SMD | R38 | RESC0402(1005)_L | CMP-009-00095-2 | 1
330R2J | 330R 0.063W 5% 0402 (1005 Metric) SMD | R39 | RESC0402(1005)_L | CMP-009-00095-2 | 1
330R2J | 330R 0.063W 5% 0402 (1005 Metric) SMD | R40 | RESC0402(1005)_L | CMP-009-00095-2 | 1
330R2J | 330R 0.063W 5% 0402 (1005 Metric) SMD | R41 | RESC0402(1005)_L | CMP-009-00095-2 | 1
330R2J | 330R 0.063W 5% 0402 (1005 Metric) SMD | R42 | RESC0402(1005)_L | CMP-009-00095-2 | 1
330R2J | 330R 0.063W 5% 0402 (1005 Metric) SMD | R43 | RESC0402(1005)_L | CMP-009-00095-2 | 1
330R2J | 330R 0.063W 5% 0402 (1005 Metric) SMD | R44 | RESC0402(1005)_L | CMP-009-00095-2 | 1
330R2J | 330R 0.063W 5% 0402 (1005 Metric) SMD | R45 | RESC0402(1005)_L | CMP-009-00095-2 | 1
330R2J | 330R 0.063W 5% 0402 (1005 Metric) SMD | R46 | RESC0402(1005)_L | CMP-009-00095-2 | 1
330R2J | 330R 0.063W 5% 0402 (1005 Metric) SMD | R47 | RESC0402(1005)_L | CMP-009-00095-2 | 1
330R2J | 330R 0.063W 5% 0402 (1005 Metric) SMD | R48 | RESC0402(1005)_L | CMP-009-00095-2 | 1
330R2J | 330R 0.063W 5% 0402 (1005 Metric) SMD | R49 | RESC0402(1005)_L | CMP-009-00095-2 | 1
330R2J | 330R 0.063W 5% 0402 (1005 Metric) SMD | R50 | RESC0402(1005)_L | CMP-009-00095-2 | 1
330R2J | 330R 0.063W 5% 0402 (1005 Metric) SMD | R51 | RESC0402(1005)_L | CMP-009-00095-2 | 1
330R2J | 330R 0.063W 5% 0402 (1005 Metric) SMD | R52 | RESC0402(1005)_L | CMP-009-00095-2 | 1
330R2J | 330R 0.063W 5% 0402 (1005 Metric) SMD | R53 | RESC0402(1005)_L | CMP-009-00095-2 | 1
330R2J | 330R 0.063W 5% 0402 (1005 Metric) SMD | R54 | RESC0402(1005)_L | CMP-009-00095-2 | 1
330R2J | 330R 0.063W 5% 0402 (1005 Metric) SMD | R55 | RESC0402(1005)_L | CMP-009-00095-2 | 1
330R2J | 330R 0.063W 5% 0402 (1005 Metric) SMD | R56 | RESC0402(1005)_L | CMP-009-00095-2 | 1
330R2J | 330R 0.063W 5% 0402 (1005 Metric) SMD | R57 | RESC0402(1005)_L | CMP-009-00095-2 | 1
330R2J | 330R 0.063W 5% 0402 (1005 Metric) SMD | R58 | RESC0402(1005)_L | CMP-009-00095-2 | 1
330R2J | 330R 0.063W 5% 0402 (1005 Metric) SMD | R59 | RESC0402(1005)_L | CMP-009-00095-2 | 1
330R2J | 330R 0.063W 5% 0402 (1005 Metric) SMD | R60 | RESC0402(1005)_L | CMP-009-00095-2 | 1
330R2J | 330R 0.063W 5% 0402 (1005 Metric) SMD | R61 | RESC0402(1005)_L | CMP-009-00095-2 | 1
330R2J | 330R 0.063W 5% 0402 (1005 Metric) SMD | R62 | RESC0402(1005)_L | CMP-009-00095-2 | 1
Resistor 1k +/-5% 0402 63 mW | Chip Resistor, 1 KOhm, +/- 5%, 0.063 W, -55 to 155 degC, 0402 (1005 Metric) | R63 | RESC1005X40X25ML10T10 | CMP-009-00013-5 | 1
DC08-11SRWA | DISPLAY 660NM RED 2DIG 0.8" 7SEG | Room_Doctor | FP-DC08-11SRWA-MFG | CMP-44525-000001-1 | 1 | Kingbright
25436NAH6 | SWITCH SLIDE SPDT 4A 125V | SW0 | FP-25436NAH6-MFG | CMP-47022-000005-1 | 1
25436NAH6 | SWITCH SLIDE SPDT 4A 125V | SW1 | FP-25436NAH6-MFG | CMP-47022-000005-1 | 1
25436NAH6 | SWITCH SLIDE SPDT 4A 125V | SW2 | FP-25436NAH6-MFG | CMP-47022-000005-1 | 1
25436NAH6 | SWITCH SLIDE SPDT 4A 125V | SW3 | FP-25436NAH6-MFG | CMP-47022-000005-1 | 1
25436NAH6 | SWITCH SLIDE SPDT 4A 125V | SW4 | FP-25436NAH6-MFG | CMP-47022-000005-1 | 1
25436NAH6 | SWITCH SLIDE SPDT 4A 125V | SW5 | FP-25436NAH6-MFG | CMP-47022-000005-1 | 1
25436NAH6 | SWITCH SLIDE SPDT 4A 125V | SW6 | FP-25436NAH6-MFG | CMP-47022-000005-1 | 1
25436NAH6 | SWITCH SLIDE SPDT 4A 125V | SW7 | FP-25436NAH6-MFG | CMP-47022-000005-1 | 1
AMS1117-3.3 | LDO Voltage Regulators 1A, 3.3V | U1 | FP-AMS1117-IPC_C | CMP-209535-000001-1 | 1 | Advanced Monolithic Systems
LD1117S18CTR | Fixed Low Drop Positive Voltage Regulator, 1.8V, 4-Pin SOT-223, Tape and Reel | U2 | SOT-223_M | CMP-0244-00315-1 | 1
LD49300PT10R | 3A Very Low Drop for Low Output Voltage Regulator, 1.0V, 5-Pin PPAK, Tape and Reel | U3 | PPAK_N | CMP-0244-00172-1 | 1
691701310004B | Terminal Block, 3.81MM Pitch, Vertical Pcb Header, Thr Type, 4 Pins | UART_HEADER | 691701310004B | CMP-1502-01983-3 | 1

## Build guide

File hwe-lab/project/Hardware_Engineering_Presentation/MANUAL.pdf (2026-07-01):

# FPGA-Based Smart Hospital Emergency Response Dispatcher

## User Manual

Board: Digilent Nexys A7-100T (Artix-7 XC7A100T) Tool: Xilinx Vivado (VHDL-2008)
Course: 6th Semester Hardware Engineering — HSHL

## 1. System Overview

This system simulates a hospital emergency dispatch unit implemented entirely in hardware on an FPGA. A patient is registered via slide switches and a button press. The system then steps through a series of states — triage, resource allocation, dispatch, treatment monitoring, and release — all controlled manually via push buttons so each step is visible in real time on the board.

The system supports up to 4 simultaneous patients using the park feature, and individual patients can be released selectively using the release mode.

## 2. Board Layout

2.1 Push Buttons

Button | Location | Function
CPU_RESETN | Bottom left Hard reset — clears everything
BTNL | Left | Register new patient
BTNC | Centre | Step FSM forward / confirm release
BTNR | Right | Emergency override (force Critical)
BTNU | Up | Park patient (keep resources busy, return to IDLE)
BTND | Down | Hold for release mode — then press BTNC to release

2.2 Slide Switches (SW7 – SW0)

SW15 SW14 SW13 SW12 SW3 | SW2 | SW1 SW0
ID3 | ID2 | ID1 | ID0 | Type1 Type0 Sev1 Sev0

Severity — SW[1:0] (rightmost)

SW1 SW0 Level

0 | 0 | Normal

SW1 SW0 Level

0 | 1 | Urgent
1 | 0 | High
1 | 1 | Critical

Type — SW[3:2] (middle)

SW3 SW2 Type

0 | 0 | General
0 | 1 | Accident
1 | 0 | Stroke
1 | 1 | Heart Attack

Patient ID — SW[15:12]: binary value 0–15 (0000 to 1111)

Note during release mode: While holding BTND, SW[1:0] selects the patient slot to release (00=slot 1, 01=slot 2, 10=slot 3, 11=slot 4). Set SW[1:0] before pressing BTNC.
2.3 LEDs
LED | | Meaning
LED[0] | | Room 1 occupied
LED[1] | | Room 2 occupied
LED[2] | | Room 3 occupied
LED[3] | | Room 4 occupied
LED[4] | | Doctor 1 occupied
LED[5] | | Doctor 2 occupied
LED[6] | | Doctor 3 occupied
LED[7] | | Doctor 4 occupied
LED[8] | | Equipment 1 in use
LED[9] | | Equipment 2 in use

LED[10] Equipment 3 in use

LED[11] Equipment 4 in use

LED[12] Critical patient flag

LED[13] Treatment active

LED[14] System fault

LED Meaning

LED[15] Alarm (blinks 2 Hz — latches until reset)

2.4 Seven-Segment Display

Eight digits read left to right:

AN7 | AN6 | AN5 | AN4 | AN3 | AN2 | AN1 | AN0

FSM state E / blank d label Doctor no. r label Room no. Severity Patient ID

FSM State codes (AN7):

Code State

0 | IDLE
1 | RECEIVE PATIENT
2 | TRIAGE
3 | CHECK RESOURCES
4 | ALLOCATE ROOM
5 | ALLOCATE DOCTOR
6 | ALLOCATE EQUIPMENT
7 | DISPATCH TEAM
8 | MONITOR TREATMENT
9 | RELEASE RESOURCES
F | FAULT

Severity labels (AN1):

Symbol Meaning

n | Normal
U | Urgent
H | High
C | Critical

AN6: Shows E when a critical patient is active or a fault has occurred. Blank otherwise.

## 3. FSM State Flow

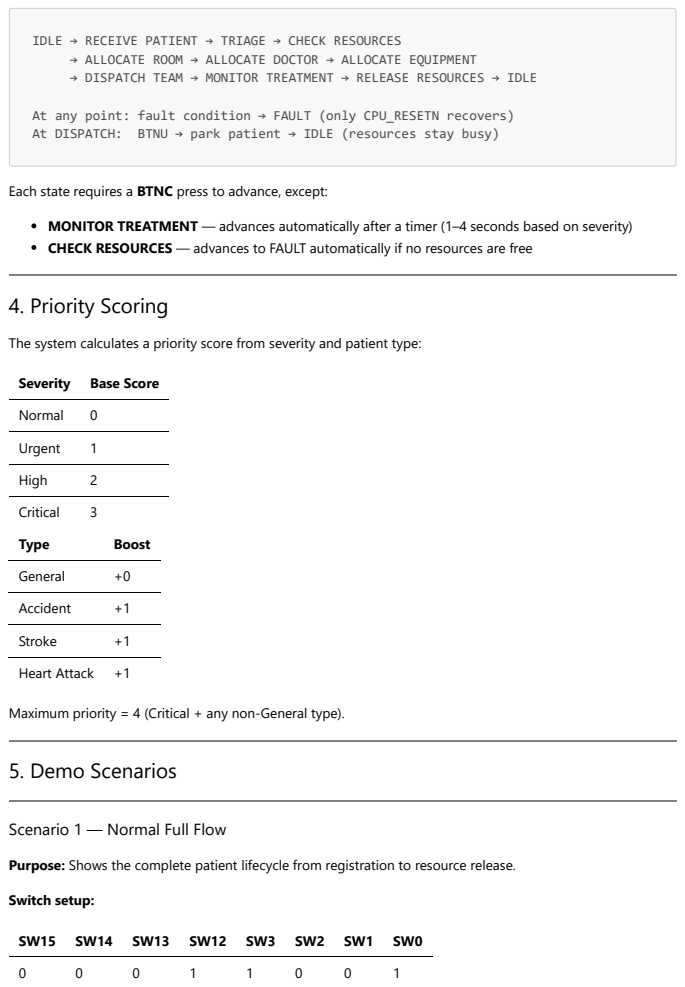
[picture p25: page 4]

IDLE → RECEIVE PATIENT → TRIAGE → CHECK RESOURCES
→ ALLOCATE ROOM → ALLOCATE DOCTOR → ALLOCATE EQUIPMENT
→ DISPATCH TEAM → MONITOR TREATMENT → RELEASE RESOURCES → IDLE

At any point: fault condition → FAULT (only CPU_RESETN recovers)
At DISPATCH: BTNU → park patient → IDLE (resources stay busy)

Each state requires a BTNC press to advance, except:

MONITOR TREATMENT — advances automatically after a timer (1–4 seconds based on severity)
CHECK RESOURCES — advances to FAULT automatically if no resources are free

The system calculates a priority score from severity and patient type:

Maximum priority = 4 (Critical + any non-General type).

Scenario 1 — Normal Full Flow

Purpose: Shows the complete patient lifecycle from registration to resource release.

ID=1, Stroke, Urgent

Step Action | Display | LEDs
1 | CPU_RESETN | 0 _ d 0 r 0 n 0 | All off
2 | BTNL | 1 _ d 0 r 0 U 1 | —
3 | BTNC — TRIAGE | 2 _ d 0 r 0 U 1 | —
4 | BTNC — CHECK | 3 _ d 0 r 0 U 1 | —
5 | BTNC — ALLOC ROOM | 4 _ d 0 r 1 U 1 | LED[0] on
6 | BTNC — ALLOC DOCTOR 5 _ d 1 r 1 U 1 | LED[4] on
7 | BTNC — ALLOC EQUIP | 6 _ d 1 r 1 U 1 | LED[8] on
8 | BTNC — DISPATCH | 7 _ d 1 r 1 U 1 | LED[13] on
9 | BTNC — MONITOR | 8 _ d 1 r 1 U 1 | wait ~2 seconds
10 | Auto — RELEASE | 9 _ d 1 r 1 U 1 | LED[0,4,8] off
11 | BTNC — IDLE | 0 _ d 0 r 0 n 0 | All off

Scenario 2 — Critical Heart Attack

Purpose: Shows maximum priority patient, critical flag, and longer treatment timer.

Switch setup:

SW15 SW14 SW13 SW12 SW3 SW2 SW1 SW0

0 | 1 | 1 | 1 | 1 | 1 | 1 | 1

ID=7, Heart Attack, Critical

Step Action | Display | LEDs
1 | CPU_RESETN | 0 _ d 0 r 0 n 0 | All off
2 | BTNL | 1 _ d 0 r 0 C 7 | —
3 | BTNC — TRIAGE | 2 E d 0 r 0 C 7 | LED[12] on
4 | BTNC — CHECK | 3 E d 0 r 0 C 7 | —
5 | BTNC — ALLOC ROOM | 4 E d 0 r 1 C 7 | LED[0] on
6 | BTNC — ALLOC DOCTOR 5 E d 1 r 1 C 7 | LED[4] on
7 | BTNC — ALLOC EQUIP | 6 E d 1 r 1 C 7 | LED[8] on
8 | BTNC — DISPATCH | 7 E d 1 r 1 C 7 | LED[13] on
9 | BTNC — MONITOR | 8 E d 1 r 1 C 7 | wait ~4 seconds

Step Action | Display | LEDs
10 | Auto — RELEASE | 9 E d 1 r 1 C 7 | LED[0,4,8] off
11 | BTNC — IDLE | 0 _ d 0 r 0 n 0 | LED[12] off

Scenario 3 — Emergency Override

Purpose: Shows BTNR forcing a Normal patient to Critical regardless of switches.

Switch setup: All switches down (Normal, General, ID=0)

Step Action | Display | LEDs
1 | CPU_RESETN | 0 _ d 0 r 0 n 0 | All off
2 | BTNR (override latch) | no change | —
3 | BTNL | 1 _ d 0 r 0 n 0 | —
4 | BTNC — TRIAGE | 2 E d 0 r 0 C 0 | LED[12] on — forced Critical
5 | BTNC×4 — to DISPATCH 7 E d 1 r 1 C 0 | LED[0,4,8,13] on
6 | BTNC — MONITOR | 8 E d 1 r 1 C 0 | wait ~4 seconds
7 | Auto + BTNC | 0 _ d 0 r 0 n 0 | All off

Scenario 4 — Park 3 Patients (Multi-Resource Demo)

Purpose: Shows multiple patients occupying resources simultaneously using BTNU park.

Patient 1 — Urgent Stroke, ID=3

SW15 SW14 SW13 SW12 SW3 SW2 SW1 SW0

0 | 0 | 1 | 1 | 1 | 0 | 0 | 1
Step Action | Display | LEDs
1 | CPU_RESETN | 0 _ d 0 r 0 n 0 | All off
2 | BTNL | 1 _ d 0 r 0 U 3 | —
3 | BTNC×6 — to DISPATCH 7 _ d 1 r 1 U 3 | LED[0,4,8,13] on
4 | BTNU — park | 0 _ d 0 r 0 n 0 | LED[0,4,8] stay on

Patient 2 — Critical Heart Attack, ID=7

SW15 SW14 SW13 SW12 SW3 SW2 SW1 SW0

0 | 1 | 1 | 1 | 1 | 1 | 1 | 1

Step Action | Display | LEDs
5 | BTNL | 1 _ d 1 r 1 C 7 | —
6 | BTNC×6 — to DISPATCH 7 E d 2 r 2 C 7 | LED[0,1,4,5,8,9,12,13] on
7 | BTNU — park | 0 _ d 0 r 0 n 0 | LED[0,1,4,5,8,9,12] stay on

Patient 3 — High Accident, ID=A

SW15 SW14 SW13 SW12 SW3 SW2 SW1 SW0

1 | 0 | 1 | 0 | 0 | 1 | 1 | 0
Step Action | Display | LEDs
8 | BTNL | 1 _ d 2 r 2 H A | —
9 | BTNC×6 — to DISPATCH 7 _ d 3 r 3 H A | LED[0,1,2,4,5,6,8,9,10,13] on
10 | BTNU — park | 0 _ d 0 r 0 n 0 | LED[0,1,2,4,5,6,8,9,10] stay on

Result: Rooms 1, 2, 3 — Doctors 1, 2, 3 — Equipment 1, 2, 3 all busy simultaneously.

Scenario 5 — Selective Release

Purpose: Shows releasing individual parked patients by slot without affecting others.

Continue from Scenario 4 (3 patients parked in slots 1, 2, 3).

Release Patient 2 — slot 2 (Room 2, Doctor 2, Equipment 2):

Step Action | Display | LEDs
1 | Set SW[1:0]=01 (slot 2) — | —
2 | Hold BTND | — | —
3 | Press BTNC | unchanged LED[1,5,9] go OFF
4 | Release BTND | — | Room 2, Doctor 2, Equip 2 now free

Release Patient 1 — slot 1 (Room 1, Doctor 1, Equipment 1):

Step Action | Display | LEDs
5 | Set SW[1:0]=00 (slot 1) | — | —
6 | Hold BTND, press BTNC unchanged LED[0,4,8] go OFF

Patient 3 remains: LED[2,6,10] still on — Room 3, Doctor 3, Equipment 3 still occupied.

Scenario 6 — Resource Exhaustion and FAULT

Purpose: Shows the system entering FAULT when no resources are available.

Park 4 patients using Scenario 4 steps (all 4 rooms full), then register a 5th:

Step Action | Display | LEDs
1 | Park 4 patients via BTNU 0 _ d 4 r 4 _ _ | LED[0–3,4–7,8–11] all on
2 | BTNL (5th patient) | 1 _ ... | —
3 | BTNC×3 — reach CHECK 3 _ ... | —
4 | Auto — no rooms free | F E d 4 r 4 _ _ | LED[14] on, LED[15] blinks
5 | Press any button | no change | System locked
6 | CPU_RESETN | 0 _ d 0 r 0 n 0 | All off

Scenario 7 — Full Reset from Any State

Purpose: Shows CPU_RESETN clears everything instantly from any state.

Step Action | Result
1 | Press CPU_RESETN at any point Display resets to 0 _ d 0 r 0 n 0
2 | — | All LEDs off
3 | — | All resources freed
4 | — | System ready for new patient

## 6. UART Output

Connect a serial terminal (PuTTY, Tera Term) to the Nexys A7 USB COM port:

| Baud rate: 115200
Format: 8N1 (8 data bits, no parity, 1 stop bit)

On each DISPATCH the system sends: P + patient ID as ASCII hex + carriage return (\r)

Patient ID UART Output

1 | P1\r
7 | P7\r
10 (A) | PA\r
15 (F) | PF\r

## 7. Quick Reference Card

Action | Button | Condition
Register patient BTNL | FSM must be in IDLE
Step FSM | BTNC | Any state except MONITOR
Force Critical | BTNR | Press before BTNL
Park patient | BTNU | Only in DISPATCH state
Release slot | Hold BTND + press BTNC Set SW[1:0] to slot first
Hard reset | CPU_RESETN | Any time
Display | Meaning
AN7 = 0 | System idle, ready
AN7 = F | Fault — press CPU_RESETN
AN6 = E | Critical patient or fault active
AN1 = C | Critical severity
LED[14] on | Fault detected

LED[15] blinking Alarm latched

## 8. Common Issues

Symptom | Cause | Fix
BTNL has no effect | FSM not in IDLE
| | Check AN7 — step to IDLE or reset
Resources not releasing | Park mode used, not normal flow
| | Use BTND + BTNC to release slots

Display shows old patient after
park

Expected — display cleared on

| BTNU | Confirmed working — resets on park

FAULT immediately at CHECK

All 4 rooms/doctors/equipment
| busy | Release a slot or CPU_RESETN

LED[15] blinking, nothing
responds
Alarm latched in FAULT | Press CPU_RESETN

BTNC steps FSM while in release mode

BTND not held down properly

| | Hold BTND firmly before pressing BTNC

FPGA Smart Hospital Dispatcher — HSHL 6th Semester Hardware Engineering Project

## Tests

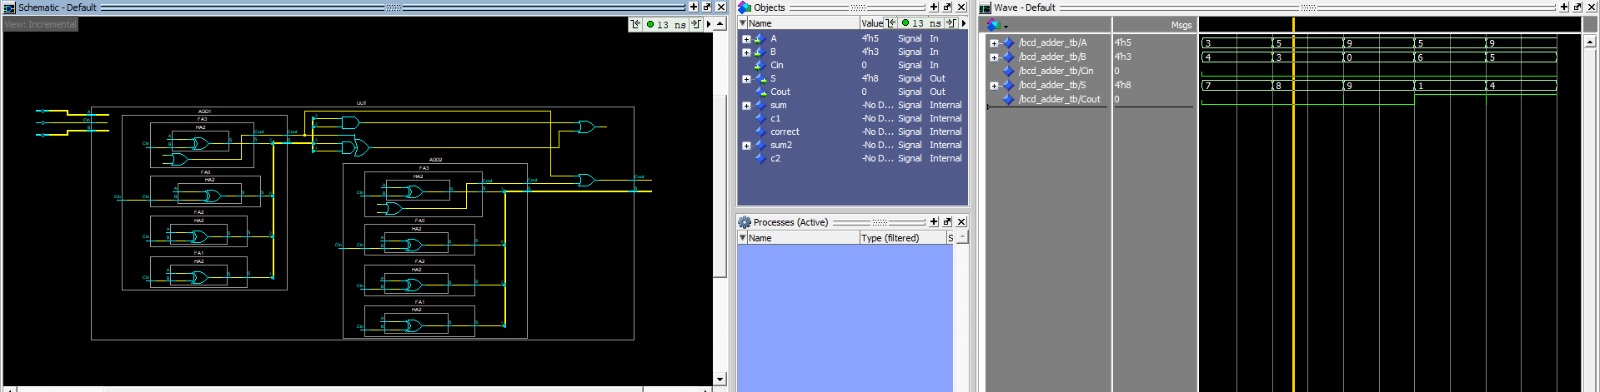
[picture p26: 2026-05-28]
hwe-lab/labs/lab02/ex04/tb_schematic/Test_Bench_Schematic.jpeg

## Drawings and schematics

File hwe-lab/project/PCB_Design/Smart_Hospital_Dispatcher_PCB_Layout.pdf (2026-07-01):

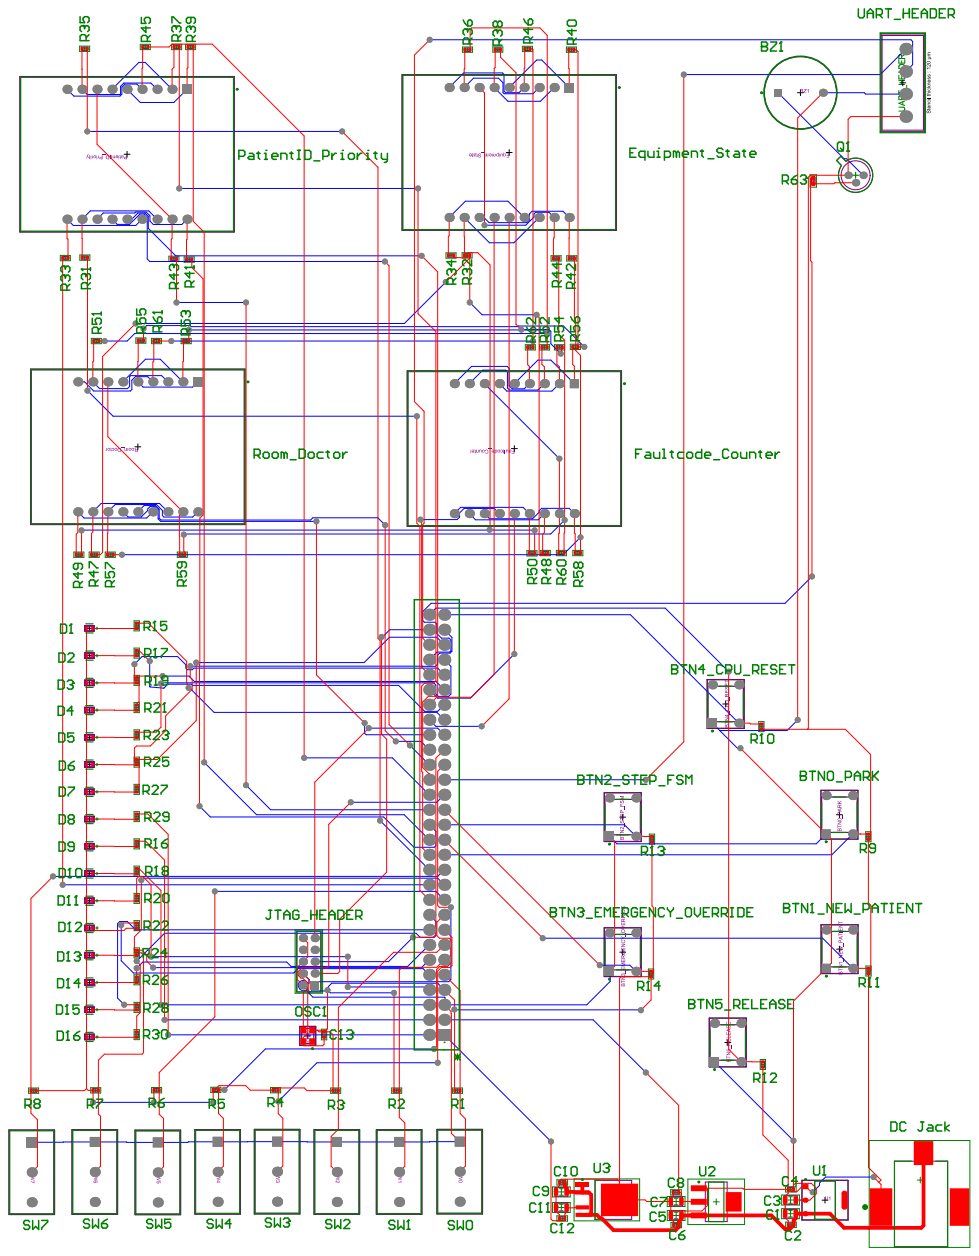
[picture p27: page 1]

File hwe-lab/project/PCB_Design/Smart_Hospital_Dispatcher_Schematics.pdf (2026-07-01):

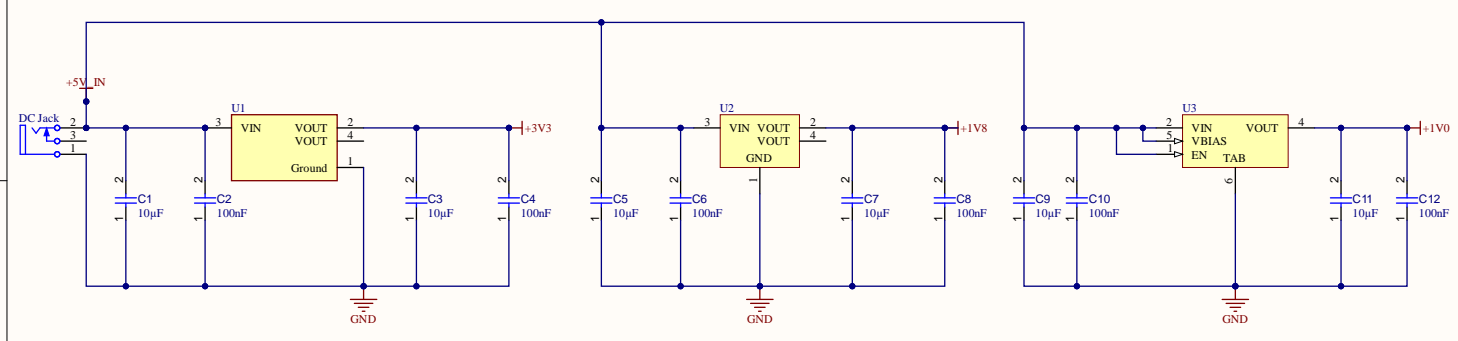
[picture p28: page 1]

Res p o n s i b le Dep t : E L E | Projec t : Smart H o s p i tal D i s patch er

D ocumen t T i t l e : 0 1 _Po wer.Sc h D o c

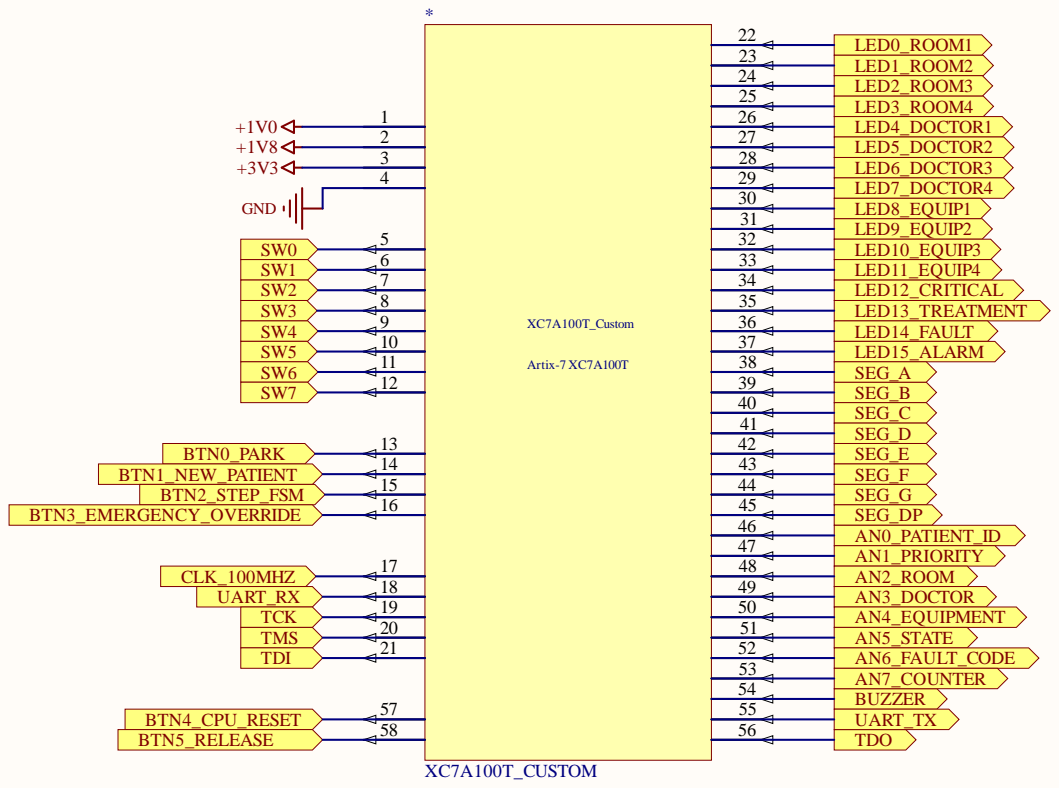
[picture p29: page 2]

Responsible Dept: ELE | Project: Smart Hospital Dispatcher

Document Title: 02_FPGA_Core.SchDoc

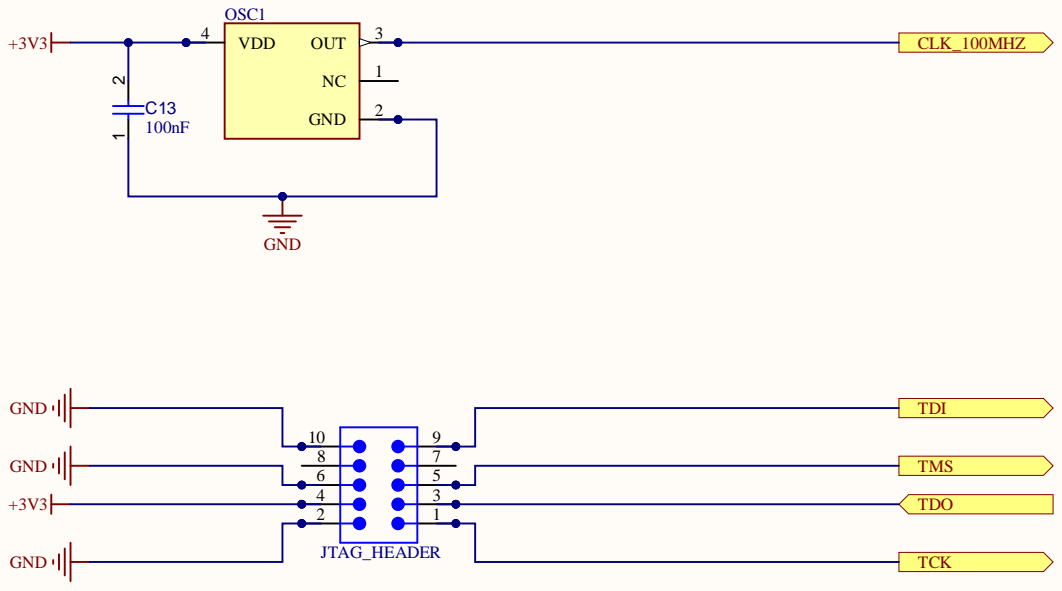
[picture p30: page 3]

Responsible Dept: ELE | Project: Smart Hospital Dispatcher

Document Title: 03_Clock_Config_JTAG.SchDoc

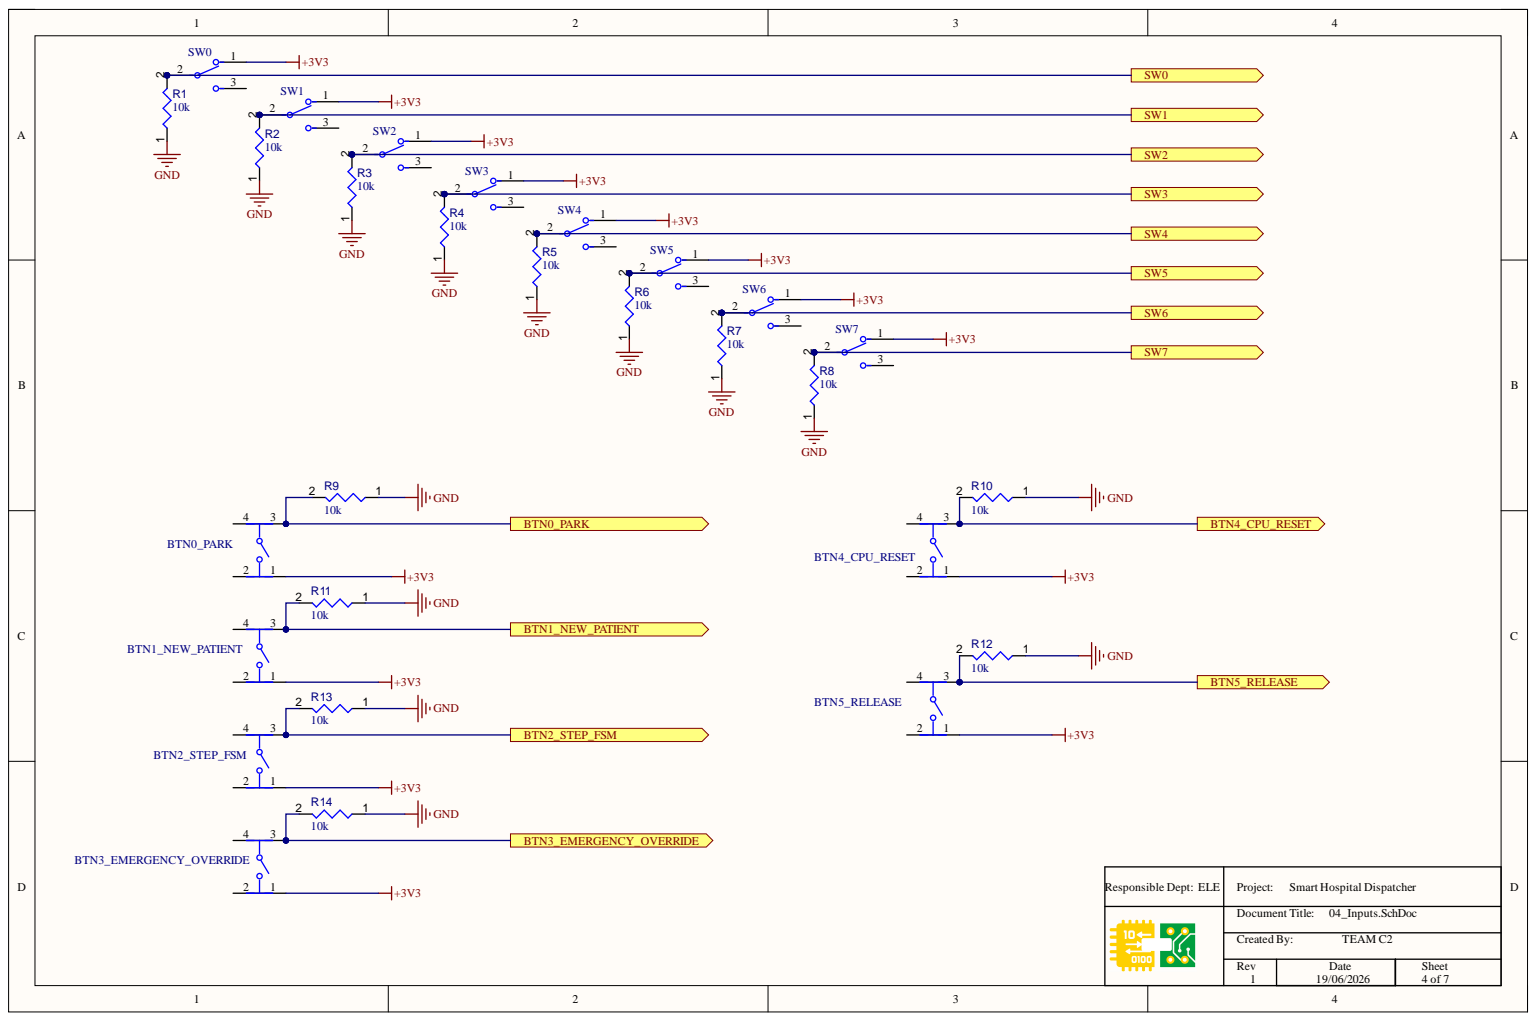
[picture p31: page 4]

Responsible Dept: ELE | Project: Smart Hospital Dispatcher

Document Title: 04_Inputs.SchDoc

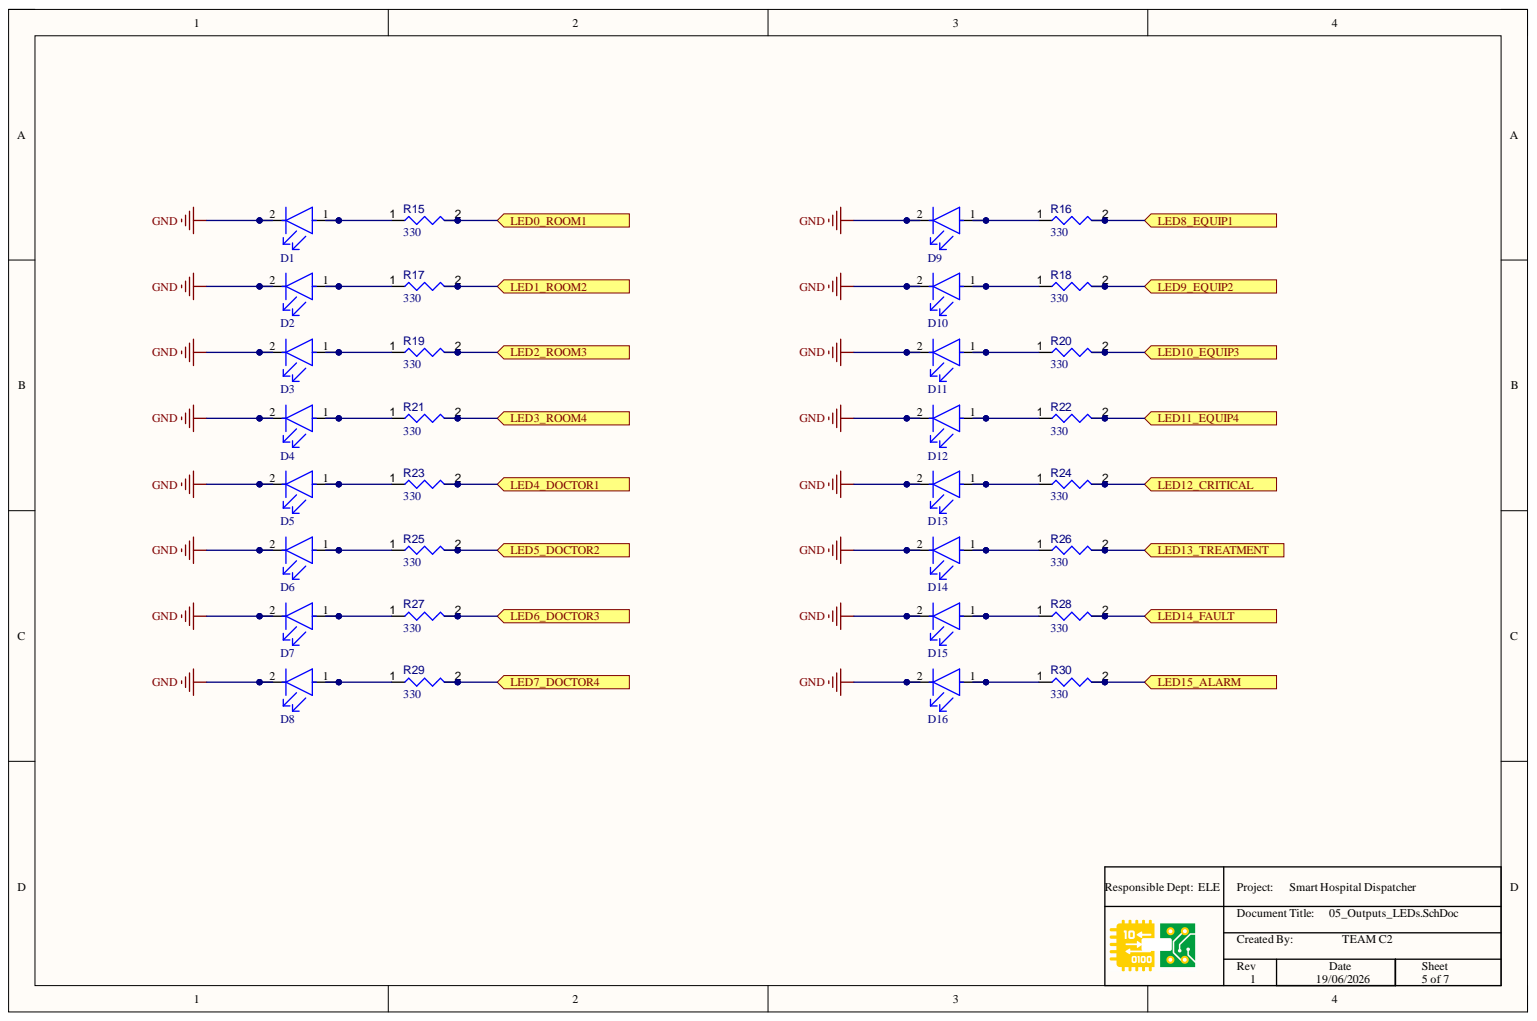
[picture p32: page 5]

Responsible Dept: ELE | Project: Smart Hospital Dispatcher

Document Title: 05_Outputs_LEDs.SchDoc

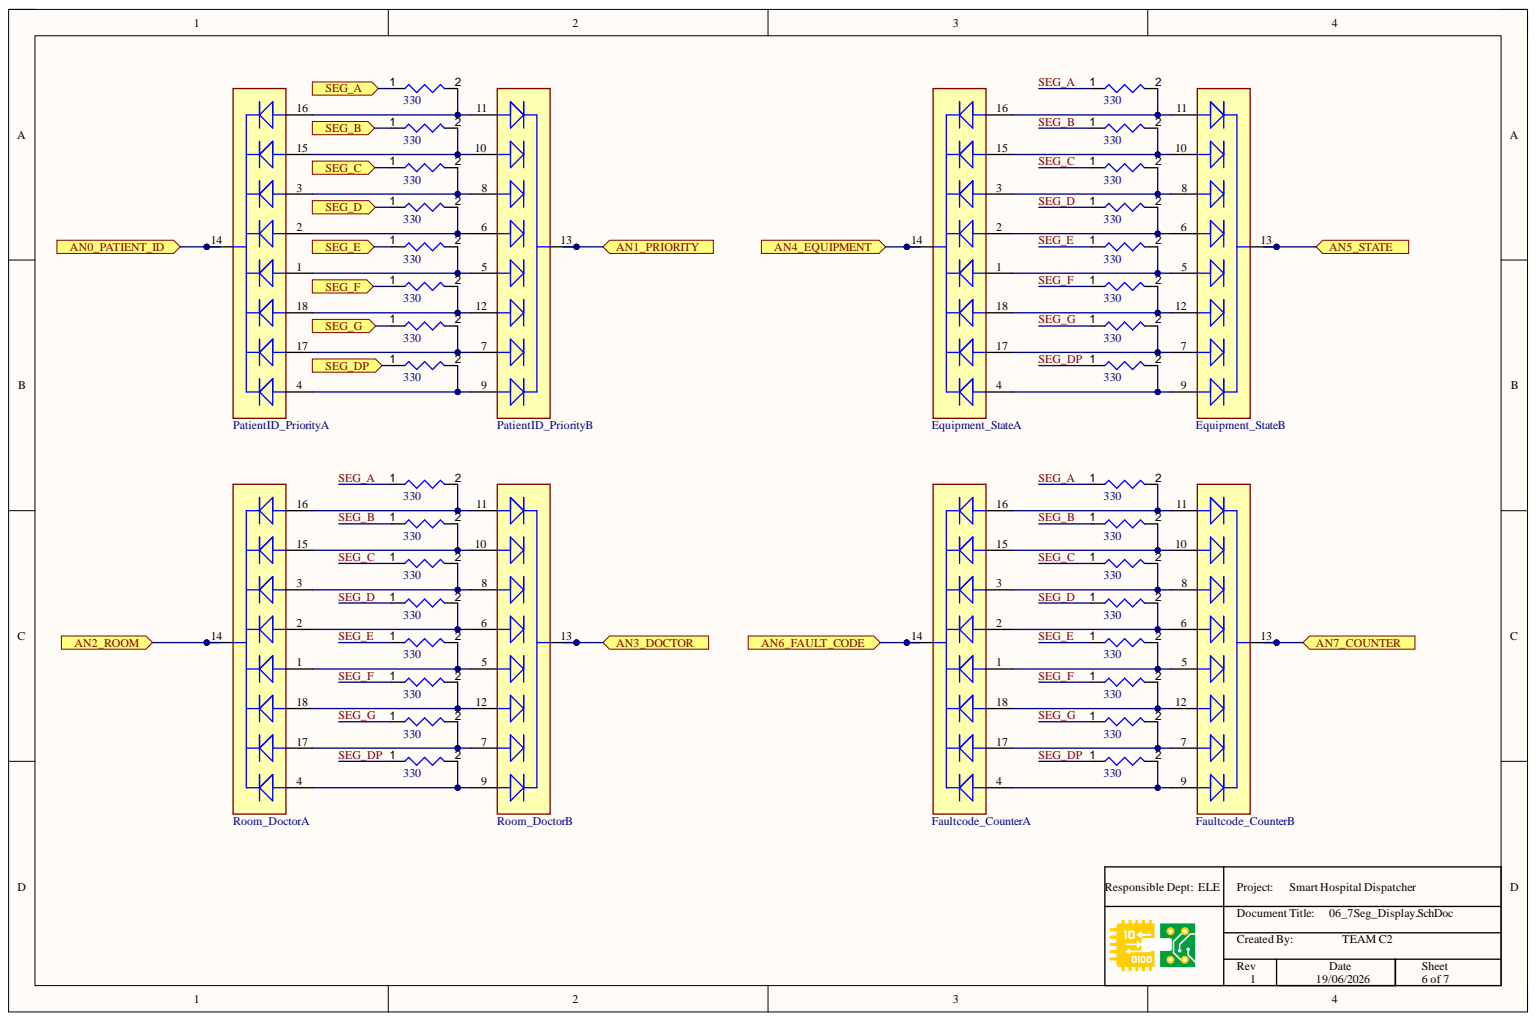
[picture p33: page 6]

Responsible Dept: ELE | Project: Smart Hospital Dispatcher

Document Title: 06_7Seg_Display.SchDoc

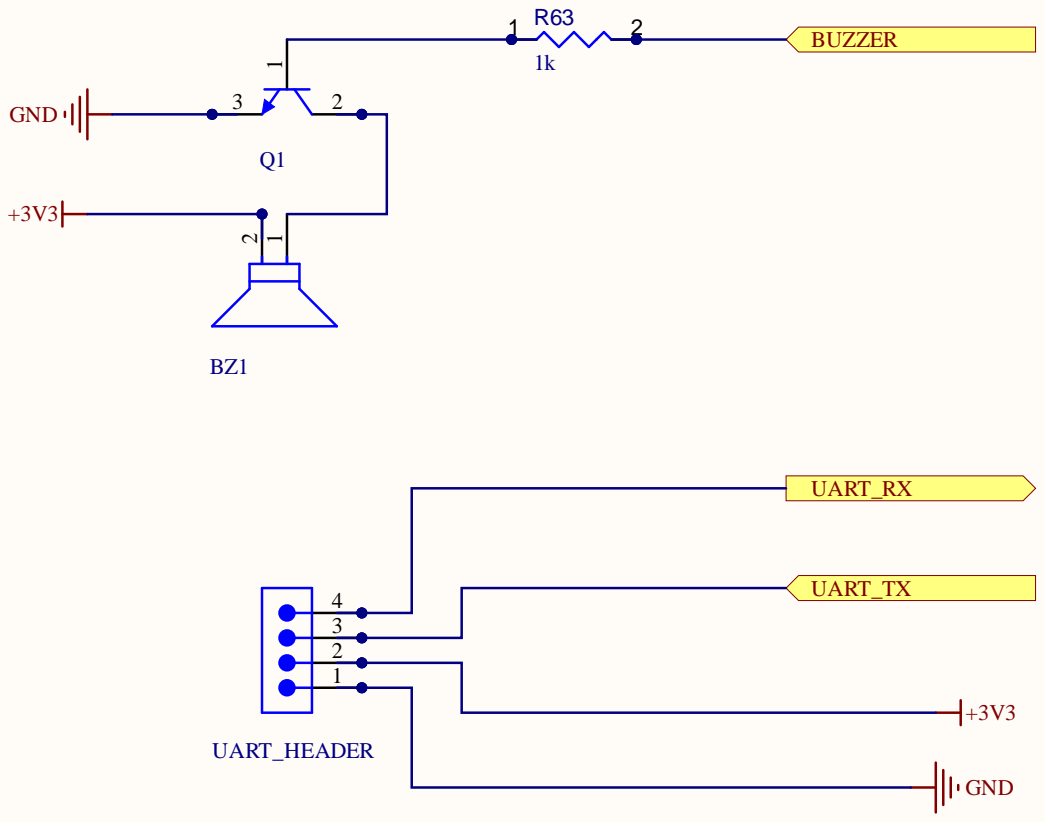
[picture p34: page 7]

Responsible Dept: ELE | Project: Smart Hospital Dispatcher

Document Title: 07_Buzzer_UART.SchDoc

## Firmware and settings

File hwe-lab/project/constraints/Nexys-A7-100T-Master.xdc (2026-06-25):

## This file is a general .xdc for the Nexys A7-100T
## To use it in a project:
## - uncomment the lines corresponding to used pins
## - rename the used ports (in each line, after get_ports) according to the top level signal names in the project

# Clock signal
set_property -dict { PACKAGE_PIN E3    IOSTANDARD LVCMOS33 } [get_ports { CLK100MHZ }]; #IO_L12P_T1_MRCC_35 Sch=clk100mhz
create_clock -add -name sys_clk_pin -period 10.00 -waveform {0 5} [get_ports {CLK100MHZ}];


##Switches
## Active mapping:
##   SW[0]  = physical SW0  -- Severity bit0  (rightmost)
##   SW[1]  = physical SW1  -- Severity bit1
##   SW[2]  = physical SW2  -- Type bit0
##   SW[3]  = physical SW3  -- Type bit1
##   SW[4]  = physical SW12 -- Patient ID bit0
##   SW[5]  = physical SW13 -- Patient ID bit1
##   SW[6]  = physical SW14 -- Patient ID bit2
##   SW[7]  = physical SW15 -- Patient ID bit3 (leftmost)
## During BTND release mode: SW[1:0] = slot select (00=slot1 01=slot2 10=slot3 11=slot4)

set_property -dict { PACKAGE_PIN J15   IOSTANDARD LVCMOS33 } [get_ports { SW[0] }]; #Sch=sw[0]  -- Severity bit0
set_property -dict { PACKAGE_PIN L16   IOSTANDARD LVCMOS33 } [get_ports { SW[1] }]; #Sch=sw[1]  -- Severity bit1
set_property -dict { PACKAGE_PIN M13   IOSTANDARD LVCMOS33 } [get_ports { SW[2] }]; #Sch=sw[2]  -- Type bit0
set_property -dict { PACKAGE_PIN R15   IOSTANDARD LVCMOS33 } [get_ports { SW[3] }]; #Sch=sw[3]  -- Type bit1
#set_property -dict { PACKAGE_PIN R17   IOSTANDARD LVCMOS33 } [get_ports { SW[x] }]; #Sch=sw[4]  -- unused
#set_property -dict { PACKAGE_PIN T18   IOSTANDARD LVCMOS33 } [get_ports { SW[x] }]; #Sch=sw[5]  -- unused
#set_property -dict { PACKAGE_PIN U18   IOSTANDARD LVCMOS33 } [get_ports { SW[x] }]; #Sch=sw[6]  -- unused
#set_property -dict { PACKAGE_PIN R13   IOSTANDARD LVCMOS33 } [get_ports { SW[x] }]; #Sch=sw[7]  -- unused
#set_property -dict { PACKAGE_PIN T8    IOSTANDARD LVCMOS18 } [get_ports { SW[x] }]; #Sch=sw[8]  -- unused
#set_property -dict { PACKAGE_PIN U8    IOSTANDARD LVCMOS18 } [get_ports { SW[x] }]; #Sch=sw[9]  -- unused
#set_property -dict { PACKAGE_PIN R16   IOSTANDARD LVCMOS33 } [get_ports { SW[x] }]; #Sch=sw[10] -- unused
#set_property -dict { PACKAGE_PIN T13   IOSTANDARD LVCMOS33 } [get_ports { SW[x] }]; #Sch=sw[11] -- unused
set_property -dict { PACKAGE_PIN H6    IOSTANDARD LVCMOS33 } [get_ports { SW[4] }]; #Sch=sw[12] -- Patient ID bit0 (SW12)
set_property -dict { PACKAGE_PIN U12   IOSTANDARD LVCMOS33 } [get_ports { SW[5] }]; #Sch=sw[13] -- Patient ID bit1 (SW13)
set_property -dict { PACKAGE_PIN U11   IOSTANDARD LVCMOS33 } [get_ports { SW[6] }]; #Sch=sw[14] -- Patient ID bit2 (SW14)
set_property -dict { PACKAGE_PIN V10   IOSTANDARD LVCMOS33 } [get_ports { SW[7] }]; #Sch=sw[15] -- Patient ID bit3 (SW15, leftmost)

## LEDs

set_property -dict { PACKAGE_PIN H17   IOSTANDARD LVCMOS33 } [get_ports { LED[0] }]; #IO_L18P_T2_A24_15 Sch=led[0]
set_property -dict { PACKAGE_PIN K15   IOSTANDARD LVCMOS33 } [get_ports { LED[1] }]; #IO_L24P_T3_RS1_15 Sch=led[1]
set_property -dict { PACKAGE_PIN J13   IOSTANDARD LVCMOS33 } [get_ports { LED[2] }]; #IO_L17N_T2_A25_15 Sch=led[2]
set_property -dict { PACKAGE_PIN N14   IOSTANDARD LVCMOS33 } [get_ports { LED[3] }]; #IO_L8P_T1_D11_14 Sch=led[3]
set_property -dict { PACKAGE_PIN R18   IOSTANDARD LVCMOS33 } [get_ports { LED[4] }]; #IO_L7P_T1_D09_14 Sch=led[4]
set_property -dict { PACKAGE_PIN V17   IOSTANDARD LVCMOS33 } [get_ports { LED[5] }]; #IO_L18N_T2_A11_D27_14 Sch=led[5]
set_property -dict { PACKAGE_PIN U17   IOSTANDARD LVCMOS33 } [get_ports { LED[6] }]; #IO_L17P_T2_A14_D30_14 Sch=led[6]
set_property -dict { PACKAGE_PIN U16   IOSTANDARD LVCMOS33 } [get_ports { LED[7] }]; #IO_L18P_T2_A12_D28_14 Sch=led[7]
set_property -dict { PACKAGE_PIN V16   IOSTANDARD LVCMOS33 } [get_ports { LED[8] }]; #IO_L16N_T2_A15_D31_14 Sch=led[8]
set_property -dict { PACKAGE_PIN T15   IOSTANDARD LVCMOS33 } [get_ports { LED[9] }]; #IO_L14N_T2_SRCC_14 Sch=led[9]
set_property -dict { PACKAGE_PIN U14   IOSTANDARD LVCMOS33 } [get_ports { LED[10] }]; #IO_L22P_T3_A05_D21_14 Sch=led[10]
set_property -dict { PACKAGE_PIN T16   IOSTANDARD LVCMOS33 } [get_ports { LED[11] }]; #IO_L15N_T2_DQS_DOUT_CSO_B_14 Sch=led[11]
set_property -dict { PACKAGE_PIN V15   IOSTANDARD LVCMOS33 } [get_ports { LED[12] }]; #IO_L16P_T2_CSI_B_14 Sch=led[12]
set_property -dict { PACKAGE_PIN V14   IOSTANDARD LVCMOS33 } [get_ports { LED[13] }]; #IO_L22N_T3_A04_D20_14 Sch=led[13]
set_property -dict { PACKAGE_PIN V12   IOSTANDARD LVCMOS33 } [get_ports { LED[14] }]; #IO_L20N_T3_A07_D23_14 Sch=led[14]
set_property -dict { PACKAGE_PIN V11   IOSTANDARD LVCMOS33 } [get_ports { LED[15] }]; #IO_L21N_T3_DQS_A06_D22_14 Sch=led[15]
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

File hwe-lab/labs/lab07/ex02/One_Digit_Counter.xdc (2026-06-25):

## ============================================================
## File: One_Digit_Counter.xdc
## Board: Nexys A7-100T
## Function: One-digit decimal counter on 7-segment display
## START_STOP = SW0, CLEAR = BTNC
## ============================================================

## Clock signal: 100 MHz system clock
set_property -dict { PACKAGE_PIN E3 IOSTANDARD LVCMOS33 } [get_ports {CLK100MHZ}]
create_clock -add -name sys_clk_pin -period 10.00 -waveform {0 5} [get_ports {CLK100MHZ}]

## Start/Stop input: SW0
set_property -dict { PACKAGE_PIN J15 IOSTANDARD LVCMOS33 } [get_ports {START_STOP}]

## Clear input: BTNC
set_property -dict { PACKAGE_PIN N17 IOSTANDARD LVCMOS33 } [get_ports {CLEAR}]

## 7-segment cathodes, active-low
set_property -dict { PACKAGE_PIN T10 IOSTANDARD LVCMOS33 } [get_ports {CA}]
set_property -dict { PACKAGE_PIN R10 IOSTANDARD LVCMOS33 } [get_ports {CB}]
set_property -dict { PACKAGE_PIN K16 IOSTANDARD LVCMOS33 } [get_ports {CC}]
set_property -dict { PACKAGE_PIN K13 IOSTANDARD LVCMOS33 } [get_ports {CD}]
set_property -dict { PACKAGE_PIN P15 IOSTANDARD LVCMOS33 } [get_ports {CE}]
set_property -dict { PACKAGE_PIN T11 IOSTANDARD LVCMOS33 } [get_ports {CF}]
set_property -dict { PACKAGE_PIN L18 IOSTANDARD LVCMOS33 } [get_ports {CG}]
set_property -dict { PACKAGE_PIN H15 IOSTANDARD LVCMOS33 } [get_ports {DP}]

## 7-segment anodes, active-low
set_property -dict { PACKAGE_PIN J17 IOSTANDARD LVCMOS33 } [get_ports {AN[0]}]
set_property -dict { PACKAGE_PIN J18 IOSTANDARD LVCMOS33 } [get_ports {AN[1]}]
set_property -dict { PACKAGE_PIN T9  IOSTANDARD LVCMOS33 } [get_ports {AN[2]}]
set_property -dict { PACKAGE_PIN J14 IOSTANDARD LVCMOS33 } [get_ports {AN[3]}]
set_property -dict { PACKAGE_PIN P14 IOSTANDARD LVCMOS33 } [get_ports {AN[4]}]
set_property -dict { PACKAGE_PIN T14 IOSTANDARD LVCMOS33 } [get_ports {AN[5]}]
set_property -dict { PACKAGE_PIN K2  IOSTANDARD LVCMOS33 } [get_ports {AN[6]}]
set_property -dict { PACKAGE_PIN U13 IOSTANDARD LVCMOS33 } [get_ports {AN[7]}]

## Recommended configuration voltage settings for Nexys A7
set_property CFGBVS VCCO [current_design]
set_property CONFIG_VOLTAGE 3.3 [current_design]

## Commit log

2026-06-18 Led controlling and patient generator files uploaded
2026-06-19 Uploaded uart controller src file
2026-06-19 Lab 04 PCB Project
2026-06-25 Update README with One Digit Counter details
    Added detailed description of the One Digit Counter implementation, including inputs, outputs, board connections, and important notes.
2026-06-25 Update led_controller.vhd final version verification upload
2026-06-25 Update patient_generator.vhd final version updated
2026-06-25 updated to final version
    Added park button input and related signals for handling patient parking functionality.
2026-06-25 Update Final Version_Refactor top_level.vhd
    Updated comments for clarity and modified signal names to reflect new functionality. Adjusted UART transmission process and added new signals for patient management.
2026-06-25 Update final version patient_table.vhd file
2026-06-25 BItstream file for the final working prototype
2026-07-01 Expand Readme with project details and specifications
    Added detailed project information including objectives, hardware features, software used, repository structure, PCB specifications, and project deliverables.
2026-07-01 BOM uploaded
    [Smart_Hospital_Dispatcher_BOM.xlsx]
2026-07-01 3d view of the PCB layout uploaded
